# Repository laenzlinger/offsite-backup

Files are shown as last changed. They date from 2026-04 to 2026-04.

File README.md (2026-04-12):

# Granit — Offsite Backup Device

Custom carrier board for the Raspberry Pi CM4 Compute Module, designed as a minimal offsite backup appliance.

## Concept

A compact, headless device that connects to a remote network and receives encrypted backups onto an attached hard disk.
Designed to be left at a trusted offsite location (friend's house, office, etc.) and managed remotely.

This PCB is designed with [KiCad 10](https://www.kicad.org/blog/2026/03/Version-10.0.0-Released/)

## Hardware

### Core Components

| Component | Description |
|---|---|
| Raspberry Pi CM4 | Compute module (PCIe Gen 2 x1). CM5 mechanically compatible but not validated for power budget |
| ASM1061 | PCIe Gen 2 x1 to 2-port SATA III controller (no firmware blob required) |
| 2.5" or 3.5" SATA HDD/SSD | Backup storage |
| Amphenol 10029364-001LF | 22-pin SATA connector (data 7-pin + power 15-pin), right-angle |
| RJ45 + Ethernet magnetics | Gigabit Ethernet |
| DS3231 RTC | Battery-backed real-time clock with alarm wake (I2C) |
| CR2032 coin cell | RTC backup battery |
| RGB LED | Status indicator (idle/backup/error/maintenance) |
| Tactile button | Manual shutdown, trigger backup, enter maintenance mode on boot |
| Hirose DF40C-100DS-0.4V(51) | 2x CM4 board-to-board connectors |
| AP64501SP-13 | 3.5A DC-DC buck converter (reused from [pedalboard-hw](https://github.com/pedalboard/pedalboard-hw)) |
| USB-C | USB 2.0 OTG connector with USBLC6-2SC6 ESD protection |
| 2N7002 + 74AHCT1G32 | Hardware wake circuit (RTC alarm → GLOBAL_EN) and SATA power gate drivers |

### Block Diagram

Architecture Diagram

### PCB 3D Render

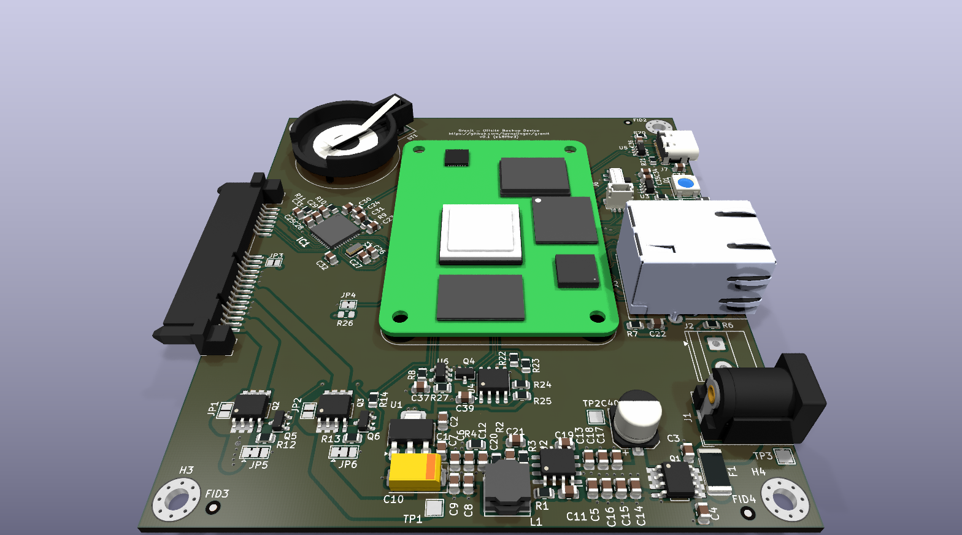
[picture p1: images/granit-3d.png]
PCB 3D


### Key Design Decisions

- **ASM1061 over USB-to-SATA bridges**: Native PCIe SATA controller using the standard Linux
  `ahci` driver. No proprietary firmware blob required — the SPI flash footprint can be left
  unpopulated. SMART works natively (`smartctl /dev/sda`) without SAT translation hacks.
  Both CM4 and CM5 have PCIe Gen 2 x1, so full SATA III throughput is available on either
  module — unlike USB-to-SATA, which would be bottlenecked by CM4's USB 2.0 (~35 MB/s).
- **12V DC input**: Required for 3.5" HDD support (spindle motor needs 12V).
  12V is passed through directly to the SATA power connector.
  AP64501SP-13 accepts 3.8–28V input, so 12V is well within range.
  Both barrel jack (Würth 6941xx301002) and screw terminal (Phoenix MKDS-1,5-2) footprints
  are provided — populate one at assembly time.
- **Reuse from pedalboard-hw**: CM connector, power supply (AP64501SP-13 buck + NCP1117 LDO),
  USB power switch (AP2553W6), KiCad symbol/footprint library, CI pipeline.
- **USB-C OTG**: Single USB-C connector for eMMC flashing (`rpiboot`) and USB mass storage
  gadget mode (initial backup seeding over USB). USB 2.0 device mode only, with USBLC6-2SC6
  ESD protection.
- **SATA power control**: 12V and 5V to the SATA connector are software-controlled via
  GPIO17. HDD is off by default at boot — powered on explicitly by software. Solder jumpers
  (JP5, JP6) allow changing the default to power-on at boot without a PCB respin.
- **Power budget**: 12V @ 2A (3.5" HDD spin-up) + 5V @ 2.3A peak (CM4 + electronics) — use a 12V/3A+ PSU.
- **Boot and storage strategy**: Full OS on CM4 eMMC (no SD card slot), SATA HDD dedicated
  to LUKS-encrypted backup storage only. HDD can spin down when idle. No SD card — eMMC is
  more reliable for a deploy-and-forget device. Reflashing via `nRPIBOOT` + USB-C if needed.

For detailed circuit design notes, PCB routing guidelines, and netclass definitions,
see [hardware/DESIGN.md](hardware/DESIGN.md).

## Software

The device runs Raspberry Pi OS Lite (headless).

### Planned Stack

- Restic backup repository (encryption built-in)
- rsync to receive backups from NAS
- `smartmontools` for disk health monitoring (`smartctl /dev/sda`)
- WireGuard VPN for remote management
- RTC-based scheduled wake: DS3231 alarm → GPIO4 interrupt → CM wakes from suspend → backup runs → suspend
  (`GLOBAL_EN` tied high via pull-up, CM4 uses Linux `rtcwake` for suspend/resume.
  Hardware power-off wake via MOSFET latch on `GLOBAL_EN` planned for v2.)
- LUKS full-disk encryption on the backup drive
- Automatic drive mount and health monitoring

### HDD Power Control

GPIO17 (`SATA_PWR_EN`) controls the P-FET power switches for the SATA 12V and 5V rails.
The boot default is selected by solder jumpers JP5 and JP6 (see Design Considerations above).

**Connect sequence** (power on → detect → mount):
```bash
#!/bin/bash
# Power on SATA rails (GPIO high → N-FET on → P-FET gate low → P-FET on)
gpioset gpiochip0 17=1
sleep 2

# Rescan AHCI bus (ASM1061 hot-plug)
echo "- - -" > /sys/class/scsi_host/host0/scan
sleep 3

# Unlock and mount
cryptsetup luksOpen /dev/sda1 backup
mount /dev/mapper/backup /mnt/backup
```

**Disconnect sequence** (unmount → spin down → power off):
```bash
#!/bin/bash
# Unmount and close LUKS
umount /mnt/backup
cryptsetup luksClose backup

# Spin down platters
hdparm -Y /dev/sda
sleep 1

# Remove SCSI device before power cut
echo 1 > /sys/block/sda/device/delete

# Power off SATA rails (GPIO low → N-FET off → pull-up → P-FET off)
gpioset gpiochip0 17=0
```

### Deployment

1. Initial backup on-site: connect Granit to local network, run full backup over LAN
2. Move device to offsite location (friend's house, office, etc.)
3. Plug in Ethernet + power — done
4. Subsequent backups are incremental and run automatically over WireGuard

### Monitoring & Alerting

Monitoring must live outside the Granit device — if the device fails, it can't alert about
its own failure. The device reports in after each backup run using a dead man's switch pattern:

- After each successful backup, Granit pings a healthcheck endpoint (e.g. self-hosted or healthchecks.io)
- If the expected ping doesn't arrive, an alert is triggered (email, push notification)
- Reported metrics: backup success/failure, SMART disk health, disk space remaining
- WireGuard connectivity is implicitly monitored — no tunnel means no ping

## Enclosure

Metal enclosure designed for a plug-and-forget deployment. The device should be installable
by a non-technical person: plug in Ethernet, plug in power, done.

### Hammond 1455 Series

Same PCB (92 × 100mm) fits both cases, held by a 3D printed internal frame.
PCB and HDD sit side-by-side along the enclosure length, SATA connector direct-mates between them.

| | 1455L2201 (Slim) | 1455T2601 (Wide) |
|---|---|---|
| Dimensions | 220 × 103 × 30.5 mm | 260 × 160 × 51.5 mm |
| Internal width | ~100 mm | ~157 mm |
| Internal height | ~27 mm | ~48 mm |
| HDD support | 2.5" only | 2.5" or 3.5" |
| Material | Extruded aluminium | Extruded aluminium |
| Colors | Natural, Black, Blue, Red | Natural, Black, Blue, Red |
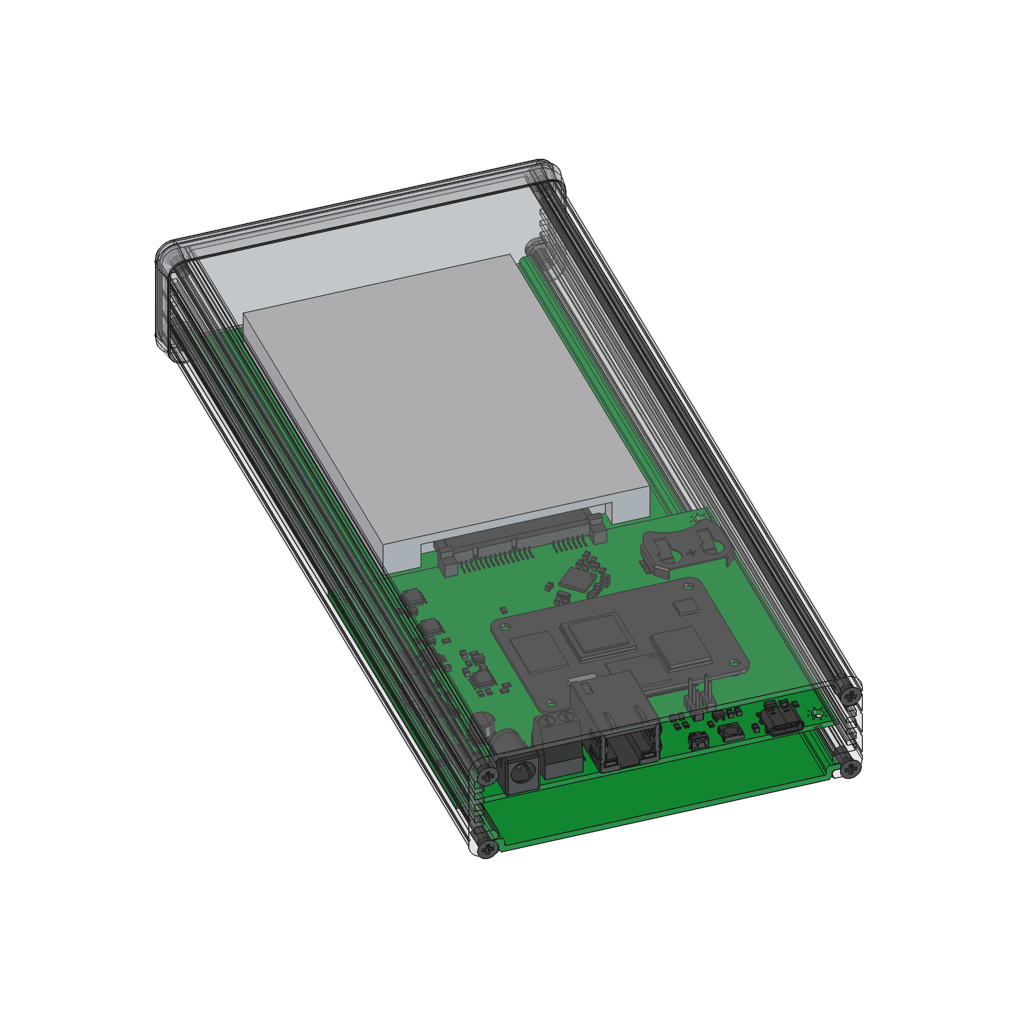
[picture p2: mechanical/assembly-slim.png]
Slim
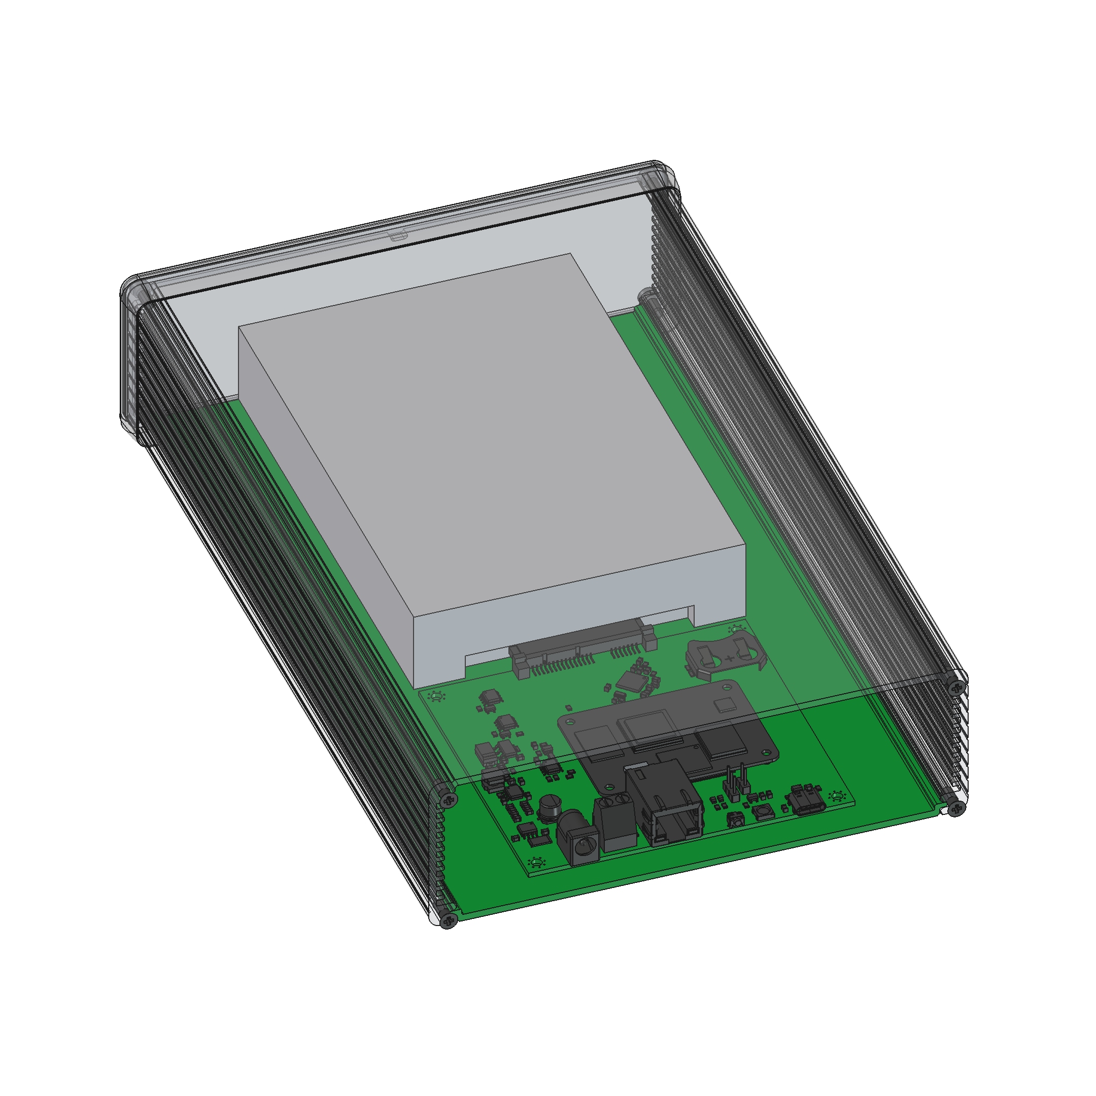
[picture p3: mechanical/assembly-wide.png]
Wide
| Assembly |  |  |

### Requirements

- Cutouts: barrel jack or screw terminal (12V), RJ45 (Ethernet), USB-C
- Tactile button accessible from outside (recessed to prevent accidental press)
- RGB LED visible through enclosure (light pipe or translucent window)
- Thermal pad or heatsink contact for CM4 SoC to enclosure lid
- Internal mounting for 2.5" or 3.5" HDD (M4 mounting holes)
- PCB standoffs (M3 mounting holes)

## Generated Hardware Documentation

Browse the latest generated outputs at **[laenzlinger.github.io/granit](https://laenzlinger.github.io/granit/)**.

Includes schematic PDF, interactive BOM, HTML BOM, and PCB prints — auto-generated on every push with [KiBot](https://github.com/INTI-CMNB/KiBot) (dev branch) running inside the official [kicad/kicad:10.0](https://hub.docker.com/r/kicad/kicad) container.

## License

[CERN Open Hardware Licence Version 2 - Permissive](https://ohwr.org/cern_ohl_p_v2.txt)

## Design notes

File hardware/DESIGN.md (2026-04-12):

# Hardware Design Notes

Detailed design decisions and PCB routing guidelines for the Granit carrier board.

## SATA Power Switching

12V and 5V to the SATA connector are switched by P-channel MOSFETs
(Q2, Q3 — FDS4435BZ). GPIO17 (`SATA_PWR_EN`) drives N-channel level shifters
(Q5, Q6 — 2N7002) which pull the P-FET gates low to turn them on.

```
Supply (+12V or +5VP)
  │
  JP5/JP6 pad 1 ─── [bridged default] ─── JP5/JP6 pad 2 (common)
                                              │
  JP5/JP6 pad 3 ─── GND                  R12/R13 (100K)
                                              │
                                         ┌────┴──── Q2/Q3 gate
                                         │
                                    2N7002 drain
                                         │
  SATA_PWR_EN (GPIO17) ── R14 (10K) ── 2N7002 gate
                                         │
                                    2N7002 source
                                         │
                                        GND
```

Two 3-pad solder jumpers (JP5 `SATA_12V_PWR`, JP6 `SATA_5V_PWR`) select the boot default:
- **Pads 1-2 bridged (default):** 100K pull-up to source → FETs OFF → HDD powered on by software
- **Pads 2-3 bridged:** 100K pull-down to GND → FETs ON → HDD powered at boot

GPIO17 high → N-FET on → P-FET gate low → SATA power on.
GPIO17 low or high-Z (boot default) → N-FET off → pull-up holds P-FET off.

R14 (10K) protects GPIO17 against N-FET gate-to-drain failure.

## Power Routing & Netclasses

PCB is fabricated with JLCPCB standard 4-layer stackup (1oz / 35µm copper on all layers).
Track widths are sized per IPC-2221 for outer-layer traces with 20°C temperature rise.

| Netclass | Track Width | Via (pad/drill) | Capacity (1oz, 20°C rise) | Worst-case Load | Nets |
|---|---|---|---|---|---|
| Power 12V | 3.0mm | 1.6mm / 0.8mm | ~3.5A | ~2.5A | `+12V*`, `fused`, `unfused` |
| Power 5V | 2.5mm | 1.6mm / 0.8mm | ~3.2A | ~2.8A | `+5VP`, `VBUS`, `switch` |
| Power 3V3 | 1.0mm | 0.8mm / 0.4mm | ~1.5A | ~0.6A | `+3V3` |

### Routing Guidelines

- Netclass widths are the default for main runs. Neck down to pad width over the last 1–2mm at component pads.
- Use copper pours for 12V and 5V in the PSU area where space allows.
- Use 2–3 parallel vias where power traces change layers.
- Place GND return vias near every power via.
- Keep 12V and 5V routing on top/bottom layers — do not break the inner GND planes.
- Do not route power traces under or parallel to PCIe/SATA/Ethernet differential pairs.

### Layer Strategy

- **Top layer:** PSU components and local routing, signal components
- **Inner 1 (In1.Cu):** GND plane — keep unbroken
- **Inner 2 (In2.Cu):** GND plane — keep unbroken
- **Bottom layer:** Power distribution (5V, 12V, 3.3V to rest of board), signal routing

### Signal Integrity

- **PCIe:** 100Ω differential impedance, matched length, minimize vias and stubs
- **SATA:** 100Ω differential impedance, matched length
- **Ethernet:** 100Ω differential impedance to RJ45 with magnetics
- **USB:** 90Ω differential impedance
- Power traces crossing differential pairs must cross perpendicular (90°)

### AC Coupling Capacitors

6× 100nF 0805 in series on high-speed differential pairs, all placed near the ASM1061:

- **SATA TX** (STXP_A, STXN_A): required by SATA spec (ASM1061 datasheet CTX = 75–200nF)
- **SATA RX** (SRXP_A, SRXN_A): defensive — external interface, can't guarantee drive-side caps
- **PCIe RX** (PCIE_RX_P, PCIE_RX_N): required by CM4 datasheet ("external AC coupling capacitor required")
- **PCIe TX, CLK**: not needed — CM4 has internal AC coupling
- **Ethernet**: not needed — MagJack provides galvanic isolation
- **USB**: not needed — DC-coupled by spec

### ESD Protection

- **USB-C** (J7): USBLC6-2SC6 on D+/D− — user-facing external connector, required
- **SATA** (J9): no ESD protection — internal connector inside metal enclosure, not user-accessible, AC coupling caps provide DC fault isolation
- **Ethernet** (J3): RJ45 MagJack has integrated common-mode chokes and 2kV isolation

## Power Budget

| Rail | Source | Capacity | Worst-case Load |
|---|---|---|---|
| 12V | External PSU | 3A+ recommended | ~2.5A (HDD spin-up + buck converter) |
| 5V | AP64501SP-13 | 3.5A | ~2.8A (CM4 + HDD + USB) |
| 3.3V | NCP1117 LDO | 1A | ~0.6A (ASM1061 + RTC + misc) |

Realistic steady state: ~1.5A (CM4) + 0.5A (HDD) = 2.0A on 5V rail.
HDD spin-up and CM4 peak don't occur simultaneously — SATA power is software-controlled.

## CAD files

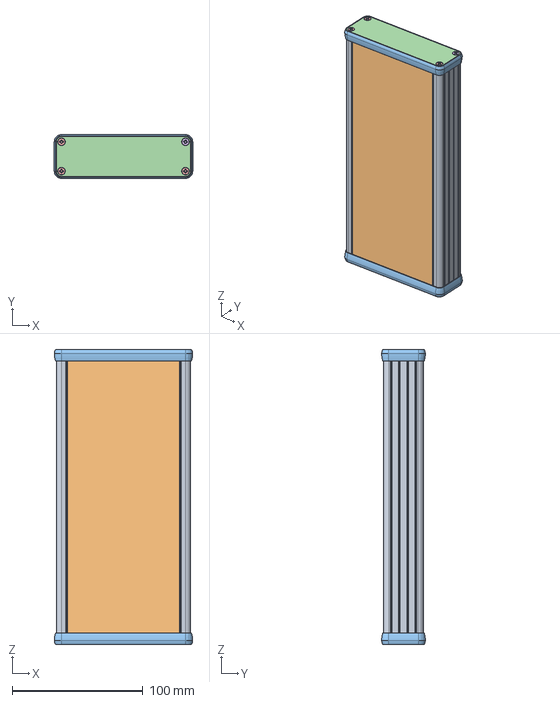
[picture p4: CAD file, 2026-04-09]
mechanical/assembly-slim.step
106.1 x 33.6 x 226.0 mm

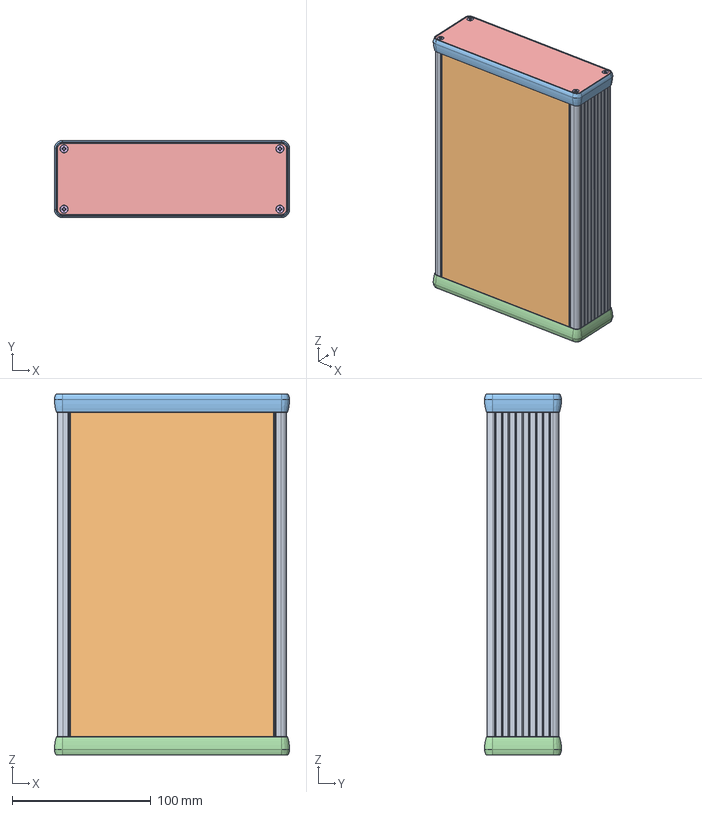
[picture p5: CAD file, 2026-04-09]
mechanical/assembly-wide.step
169.5 x 55.6 x 260.0 mm

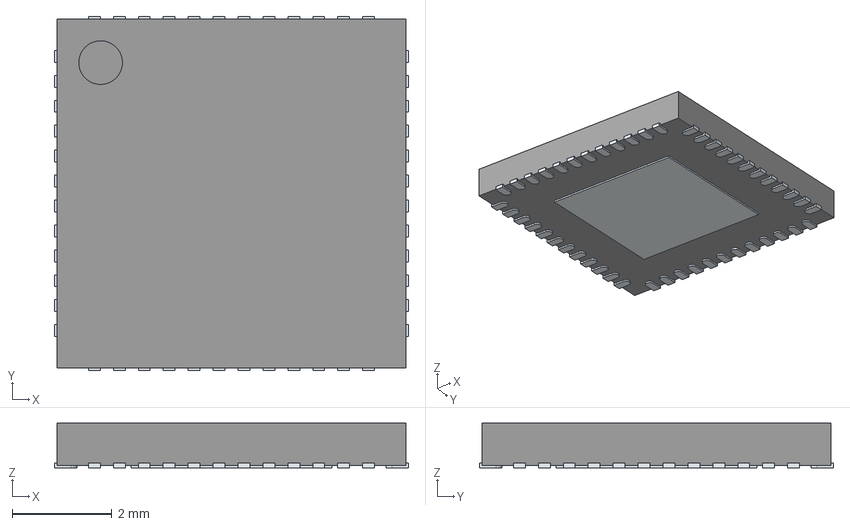
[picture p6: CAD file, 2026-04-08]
hardware/3d-models/ASM1061.stp
7.10 x 7.10 x 0.9 mm
ThermalPin
PinsArrayLR
PinsArrayTB

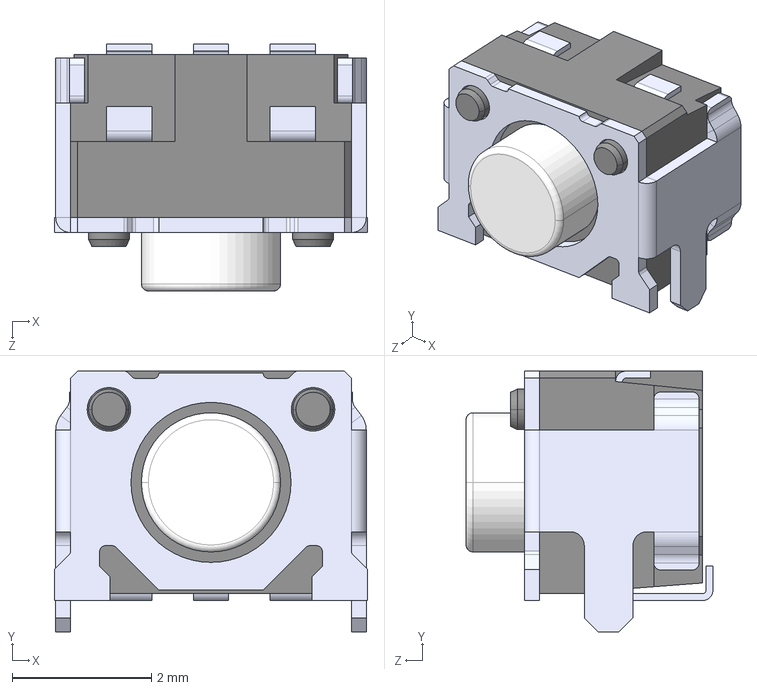
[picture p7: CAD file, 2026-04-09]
hardware/3d-models/SW_Alps_SKRTLAE010.step
4.50 x 3.75 x 3.55 mm

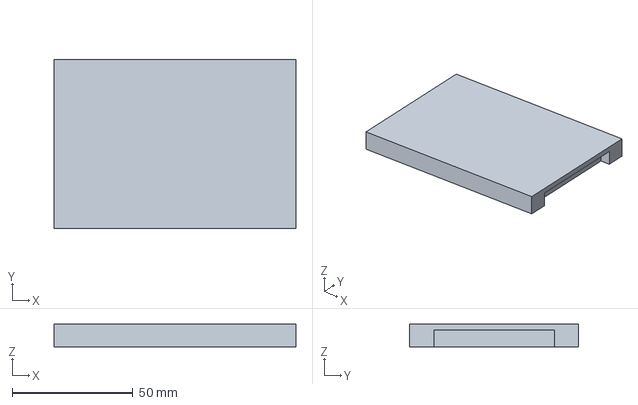
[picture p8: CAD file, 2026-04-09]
mechanical/2.5inch_HDD.step
100.2 x 69.8 x 9.50 mm

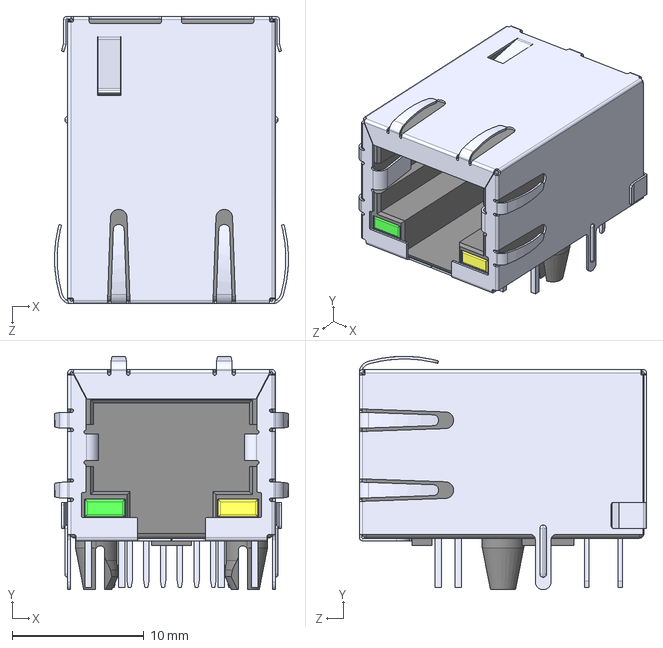
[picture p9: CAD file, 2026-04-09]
hardware/3d-models/RJ45_UDE_RB1-125B8G1A.step
17.7 x 17.7 x 21.8 mm

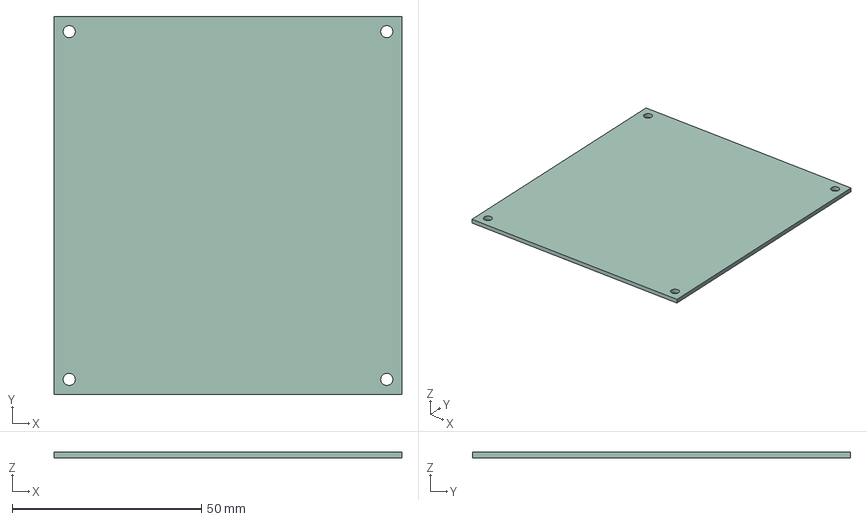
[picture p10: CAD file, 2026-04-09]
mechanical/granit-pcb.step
92.0 x 100.0 x 1.52 mm

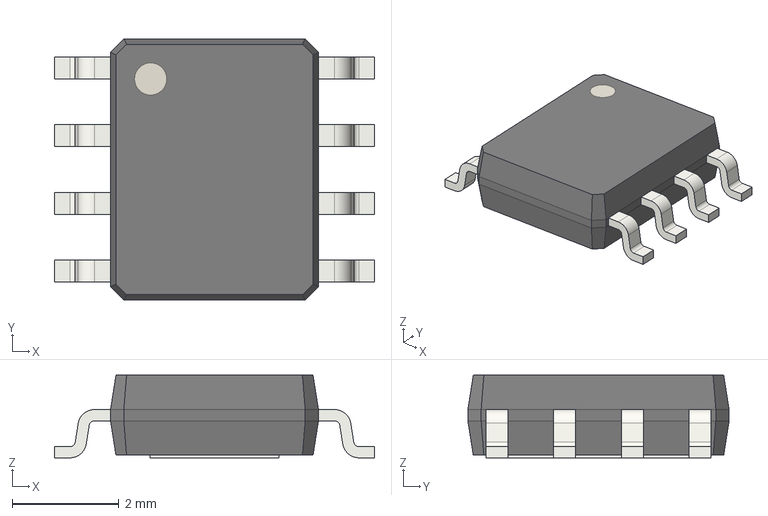
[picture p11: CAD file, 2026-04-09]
hardware/3d-models/SO-8EP.STP
6.00 x 4.90 x 1.55 mm

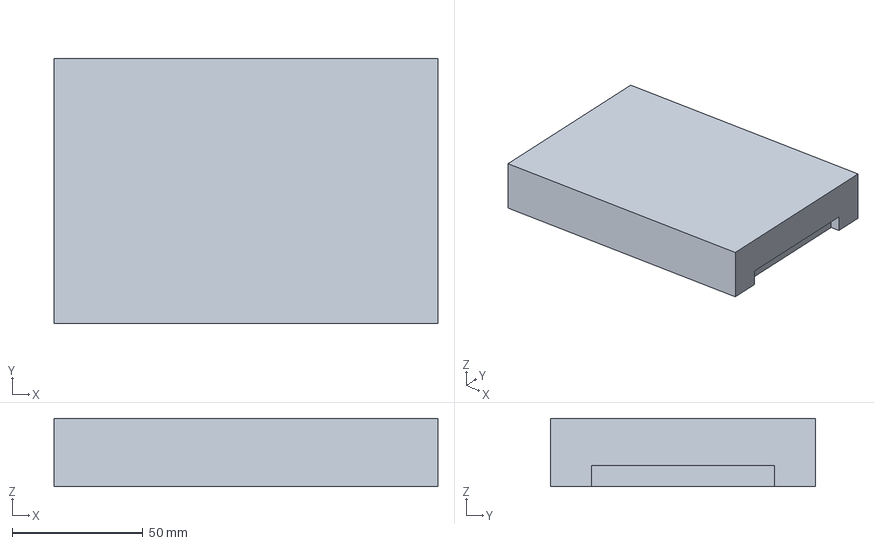
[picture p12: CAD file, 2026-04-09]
mechanical/3.5inch_HDD_NAS.step
147.0 x 101.6 x 26.1 mm

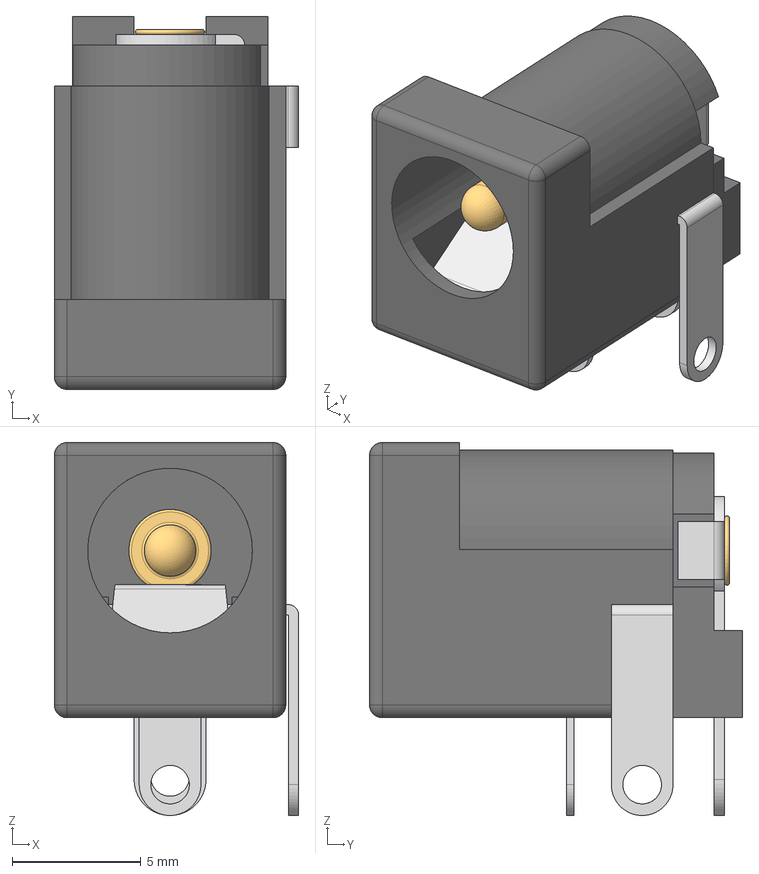
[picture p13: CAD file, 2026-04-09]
hardware/3d-models/694106301002 (rev1).stp
9.50 x 14.5 x 14.5 mm
6941xx301002
694106301002_PinContact
6941xx301002_Back
6941xx301002_PinContact2
6941xx301002_PinLame
6941xx301002_PinBis

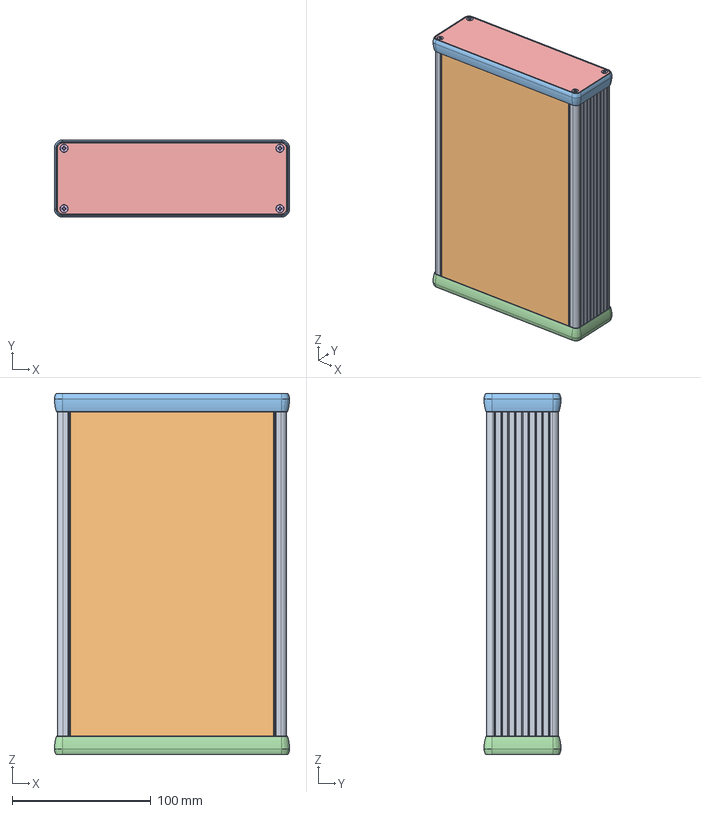
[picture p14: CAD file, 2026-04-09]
hardware/3d-models/1455T2601.stp
169.5 x 55.6 x 260.0 mm

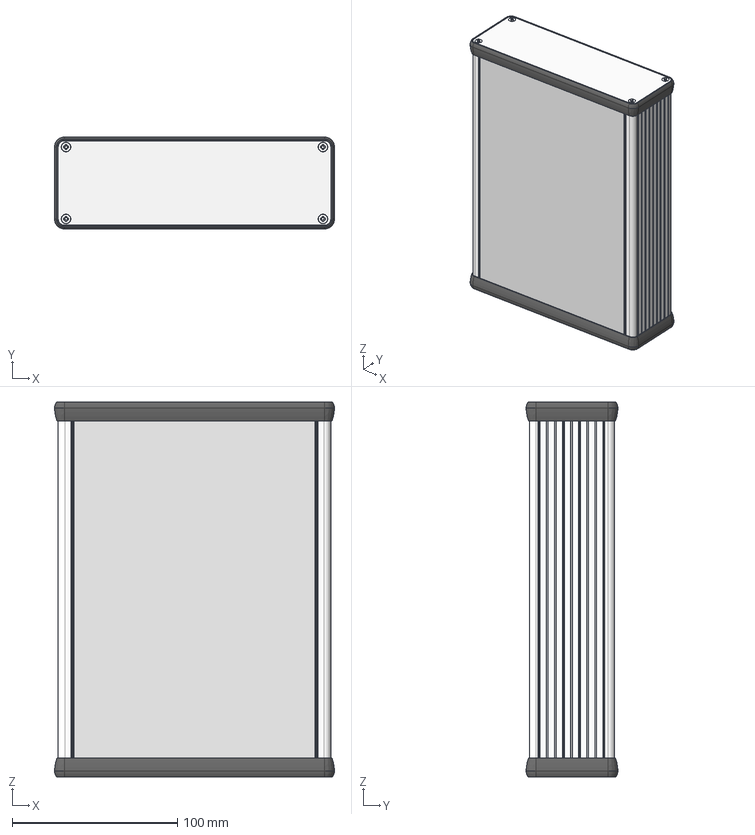
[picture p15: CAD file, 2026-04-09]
hardware/3d-models/1455T2201.stp
169.5 x 55.6 x 227.0 mm
T extrusion 220mm
T Extrusion Cap 220mm
T Bezel Open x 2
T End Plate x 2
1455 screw x 8

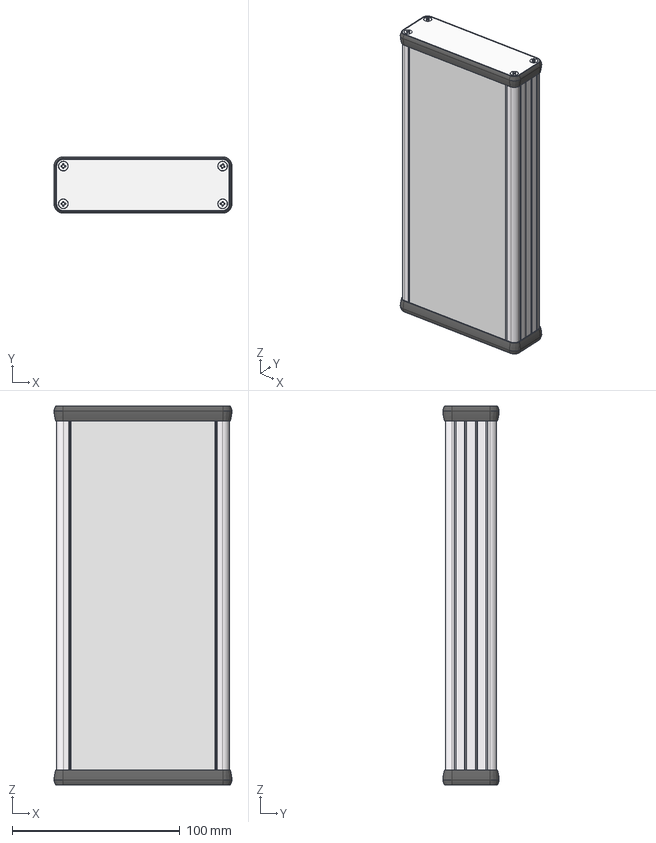
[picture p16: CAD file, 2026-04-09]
hardware/3d-models/1455L2201.stp
106.1 x 33.6 x 226.0 mm
L Extrusion 220mm
L Cap Extrusion 220mm
N Bezel x 2
N1 End Panel x 2
1455 screw x 8

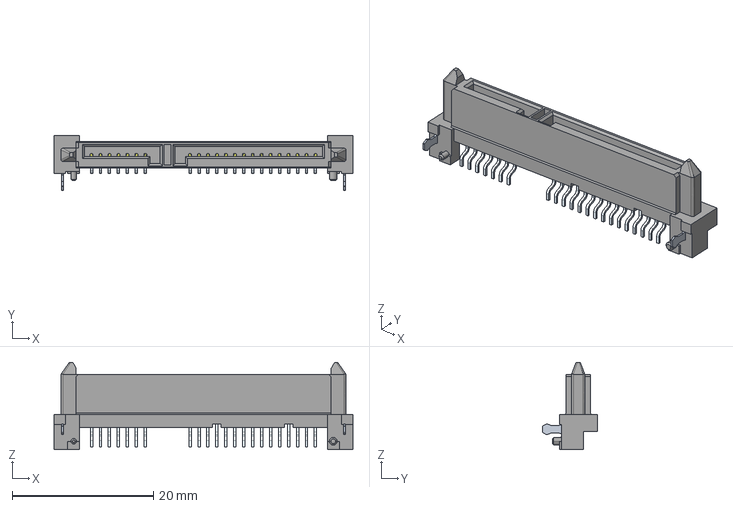
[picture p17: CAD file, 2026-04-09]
hardware/3d-models/i10029364001LF.igs
42.4 x 7.82 x 12.4 mm

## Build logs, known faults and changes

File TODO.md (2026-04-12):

# Granit — TODO

## Schematic ✅

### Done

- [x] PSU: AP64501SP-13 buck + NCP1117 LDO + FDS4435BZ reverse polarity + 3A SMD fuse
- [x] CM4 Connector 1: power, GND, NC flags, global labels, Ethernet, GLOBAL_EN
- [x] CM4 Connector 2: power, GND, NC flags, global labels, USB, PCIe
- [x] Peripherals: SK6812MINI-E NeoPixel + 74AHCT1G32 level shifter
- [x] Peripherals: status LEDs (nLED_PWR, nLED_ACT, DNP)
- [x] Peripherals: tactile button (GPIO17) + pull-up
- [x] Peripherals: nRPIBOOT PCM12SMTR slide switch
- [x] Peripherals: UART debug JST-SH 3-pin (BM03B-SRSS-TB vertical)
  - FIXME: pinout is TX-RX-GND (pins 1-2-3), standard convention is GND-TX-RX
- [x] Peripherals: DS3231MZ RTC + CR2032 battery
- [x] Peripherals: USB-C OTG + USBLC6-2SC6 ESD protection + solder jumper
- [x] Ethernet: RB1-125B8G1A Gigabit MagJack + LEDs
- [x] SATA: ASM1061 PCIe-to-SATA bridge + 25MHz crystal
- [x] SATA: add 100nF AC coupling caps (0805) in series on SATA TX pair (STXP_A, STXN_A), placed near ASM1061 — required by SATA spec (ASM1061 datasheet CTX = 75–200nF)
- [x] SATA: add 100nF AC coupling caps (0805) in series on SATA RX pair (SRXP_A, SRXN_A), placed near ASM1061 — defensive, external interface can't guarantee drive-side caps
- [x] PCIe: add 100nF AC coupling caps (0805) in series on PCIe RX pair (PCIE_RX_P, PCIE_RX_N), placed near ASM1061 TX output — CM4 datasheet: "external AC coupling capacitor required"
- [x] SATA: 7-pin data connector + 4-pin power connector
- [x] SATA: power switching (FDS4435BZ on 5V/12V, GPIO5 controlled, solder jumper bypass)
- [x] Wake: hardware power-off wake (2N7002 + 74AHCT1G32 OR gate, DNP for v1)
- [x] All footprints assigned
- [x] All component descriptions filled
- [x] Resistor values consolidated (9 unique)
- [x] All decoupling caps verified
- [x] ERC: 0 errors, 0 warnings
- [x] ERC enabled in CI

## PCB Layout

Side-by-side layout inside Hammond 1455L2201 (220mm length):

- HDD occupies 147mm, PCB sits in the remaining space
- SATA connector on PCB edge mates directly with HDD
- External connectors (RJ45, USB-C, barrel jack, button) on opposite end panel

Max PCB size: **71 × 99mm** (fits 1455L card guides at 99.5mm — compatible with both cases)

Both PCB and HDD mount independently to the belly plate (slide-out for servicing).

### Component floorplan

```
                    SATA edge (faces HDD)
    ┌─────────────────────────────────────────┐
    │                                         │
    │   ASM1061        SATA connector         │
    │   (7×7mm)        (42mm wide, edge)      │
    │      ↕ short SATA diff pairs            │
    │                                         │
    │   ────── PCIe diff pairs (~20mm) ────── │
    │                                         │
    │          CM4 module (55×40mm)            │
    │          (center of board)              │
    │                                         │
    │   ↕ short ETH     ↕ USB        PSU     │
    │   diff pairs       diff        area    │
    │                                         │
    │  RJ45  USB-C  Barrel  BTN  LED  CR2032 │
    │                                         │
    └─────────────────────────────────────────┘
                 Connector edge (end plate)
```

Placement rationale:

- ASM1061 near SATA edge → shortest SATA differential pairs
- CM4 center → PCIe north to ASM1061, Ethernet south to RJ45
- RJ45 + USB-C on connector edge → short diff pairs from CM4
- PSU in corner → switching noise away from high-speed signals
- DS3231 + CR2032 → quiet area near CM4 I2C pins
- Button + LED → connector edge, accessible through end plate

### Pre-routing: stackup and impedance (JLCPCB 4-layer)

[JLCPCB JLC04161H-7628 standard 4-layer stackup](https://jlcpcb.com/impedance) (1.6mm):

| Layer | Material | Thickness | Er |
|---|---|---|---|
| Solder mask | — | 0.6mil above trace | 3.8 |
| L1 (Top signal) | Copper | 35µm (1oz) | — |
| Prepreg | 7628 | 0.2104mm | 4.4 |
| L2 (GND plane) | Copper | 35µm (1oz) | — |
| Core | — | 1.065mm | 4.6 |
| L3 (Power plane) | Copper | 35µm (1oz) | — |
| Prepreg | 7628 | 0.2104mm | 4.4 |
| L4 (Bottom signal) | Copper | 35µm (1oz) | — |
| Solder mask | — | 0.6mil above trace | 3.8 |

Trace geometry from [JLCPCB impedance calculator](https://jlcpcb.com/impedance)
(L1 signal, L2 GND reference, 0.2104mm prepreg, Er=4.6, 1oz outer / 0.5oz inner copper):
- 100Ω differential (PCIe, SATA, Ethernet): **0.2205mm trace, 0.2032mm gap**
- 90Ω differential (USB): **0.2860mm trace, 0.2032mm gap**

[JLCPCB capabilities](https://jlcpcb.com/capabilities/pcb-capabilities):
min 0.09mm trace/space, 0.2mm drill, 0.13mm annular ring.

- [x] Choose fab house: JLCPCB (prototype)
- [x] Update KiCad net classes with calculated values:
  - PCIe: diff_pair_width=0.2205, diff_pair_gap=0.2032
  - SATA: diff_pair_width=0.2205, diff_pair_gap=0.2032
  - Ethernet: diff_pair_width=0.2205, diff_pair_gap=0.2032
  - USB: diff_pair_width=0.2860, diff_pair_gap=0.2032
- [ ] Select impedance control when ordering (+~$10)
- [x] PCB thickness: 1.6mm (standard)

### Checklist

PCB standoff height must match HDD SATA connector vertical position (~3.5mm above belly plate).

- [x] Board outline: 92 × 100mm (fits 1455L slim and 1455T2601 wide cases)
- [x] Verify PCB standoff height aligns SATA connector with HDD receptacle
- [x] 4-layer stackup (signal/GND/power/signal)
- [x] SATA connector: replaced J4+J5 with single 22-pin Amphenol 10029364-001LF (horizontal/right-angle)
  - Footprint: `Connector_SATA_SAS:SATA_Amphenol_10029364-001LF_Horizontal`
  - Symbol: `granit:SATA_22pin`
- [x] External connectors (RJ45, USB-C, barrel jack, button, LED) on opposite edge
- [x] Place CM4 module and all components on top side (facing lid, for thermal contact)
- [x] SATA connector vertical alignment: HDD connector center is 3.50mm above mounting surface (SFF-8301)
  - Use matching standoff height for PCB and HDD (e.g. 5mm) — keeps SATA aligned
  - 5mm standoffs: CR2032 (3.4mm) fits on bottom side ✅
  - 1455L: 5mm + 9.5mm (2.5" HDD) = 14.5mm, 12.5mm to ceiling ✅
  - 1455T: 5mm + 26.1mm (3.5" HDD) = 31.1mm, 17mm to ceiling ✅
- [x] CR2032 holder on bottom side (fits under 5mm standoffs)
- [x] Place ASM1061 near SATA connector (short differential pairs)
- [ ] HDD mounting holes: M4 (4.3mm drill, `MountingHole:MountingHole_4.3mm_M4_Pad_Via`)
- [x] PCB standoff holes: M3 (3.2mm drill, `MountingHole:MountingHole_3.2mm_M3_Pad_Via`)
- [ ] Mounting hole keepout: 7.0mm clearance on pads (prevent screw heads shorting 12V traces)
- [x] Route PCIe differential pairs (100Ω impedance)
- [x] Route SATA differential pairs
- [x] Route Ethernet differential pairs
- [x] Route USB differential pairs
- [x] Power trace width: ≥1.0mm (40 mil) for short branches to pads
- [ ] Power planes on L3: split into 5V and 3.3V zones
- [ ] 12V: copper pour on L4 from barrel jack to SATA power (2A+ spin-up)
- [x] GND: solid plane on L2, stitching vias throughout
- [x] GND stitching: increase via density to 3–5/cm² (currently 1.2/cm²). 3mm grid near high-speed (PCIe/SATA/ETH), 5mm elsewhere. Use Place → Add Board Stitching Vias.
- [x] DRC clean (0 violations, 46 justified exclusions)
- [ ] Silkscreen: add labels for switch positions (RUN/BOOT), jumper functions (JP1–JP6), connector pinouts (J8 UART), polarity markings, and board name/revision
- [ ] Silkscreen front: add QR code or barcode linking to project URL (https://github.com/laenzlinger/granit)
- [ ] Silkscreen back: add stackup info (layer order, impedance targets, fab spec JLC04161H-7628)

## Enclosure

- [x] Case: Hammond 1455T2201 (3.5" HDD) or 1455L2201 (2.5" HDD only)
- [ ] 3D-printed internal frame (slides into case card guide grooves)
  - Holds PCB and HDD at correct height (5mm standoff equivalent)
  - Different frame variants for 2.5" vs 3.5" HDD
  - No belly plate drilling, no standoffs, no CNC needed
- [ ] CNC end plate: cutouts for RJ45, USB-C, barrel jack, button, LED
- [ ] Thermal pad from CM4 SoC to enclosure lid

## Future Improvements

- [ ] TPM/crypto chip (e.g. ATECC608) for secure LUKS key storage (I2C)
- [ ] Evaluate CM5 compatibility (power budget validation)
- [ ] Power LED on fused 12V rail (troubleshooting: PSU present but buck failed)
- [ ] Review fuse rating: 3A may be tight for 3.5" NAS drives (1.8–2.5A spin-up) + CM4 on same rail — consider 4A or inrush limiter
- [ ] Verify ASM1061 exposed pad thermal vias to ground plane (0.5W under sustained SATA III)
- [ ] Read-only root filesystem (overlayfs) to survive power loss — eMMC-only boot has no fallback
- [ ] Second SATA data connector (7-pin) for ASM1061 port B — enables RAID1 or dual-drive backup

## CI/CD

- [x] KiBot artifact generation with KiCad 10
- [x] GitHub Pages deployment (<https://laenzlinger.github.io/granit/>)
- [x] ERC check in KiBot preflight
- [x] Enable DRC check when PCB layout is complete
- [ ] Switch to kicad10_auto container when available
- [ ] Add 3D renders (blender_export) once ghcr.io/inti-cmnb/kicad10_auto_full image exists (see pedalboard-hw)

## Software

- [ ] Raspberry Pi OS Lite base image
- [ ] Enable BCM2711 hardware watchdog (`bcm2835_wdt`) — critical for unattended remote device
- [ ] Device tree overlay for ASM1061
- [ ] DS3231 RTC driver + alarm configuration
- [ ] DS3231 OSF flag check on boot (warn if battery failed, report via healthcheck)
- [ ] GPIO_HOLD (GPIO6) assertion on boot
- [ ] SATA_PWR_EN (GPIO17) control
- [ ] NeoPixel status daemon
- [ ] Button handler (shutdown/backup/maintenance)
- [ ] WireGuard VPN configuration
- [ ] Restic backup automation
- [ ] LUKS encrypted backup partition
- [ ] Healthcheck dead man's switch
- [ ] SMART disk monitoring
- [ ] rtcwake integration for scheduled power-off/wake

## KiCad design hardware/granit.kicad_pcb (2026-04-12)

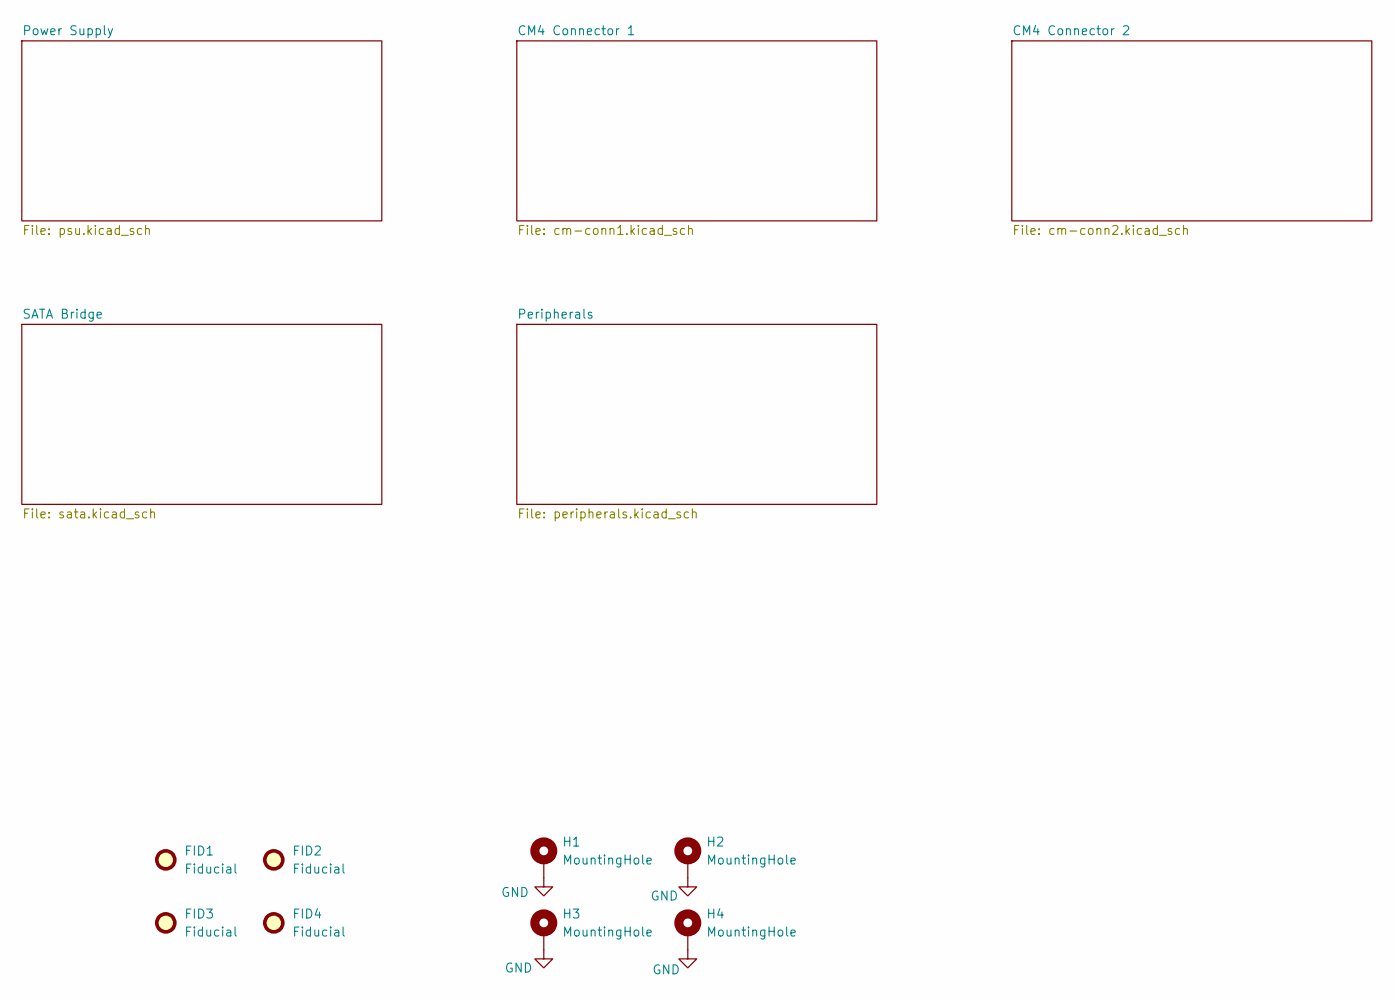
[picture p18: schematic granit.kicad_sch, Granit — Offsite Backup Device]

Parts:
FID1, FID2, FID3, FID4: Fiducial; Fiducial_1mm_Mask2mm
H1, H2, H3, H4: MountingHole; MountingHole_3.2mm_M3_Pad_Via

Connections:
GND: H1.1 (1_1), H2.1 (1_1), H3.1 (1_1), H4.1 (1_1); also elsewhere on the board

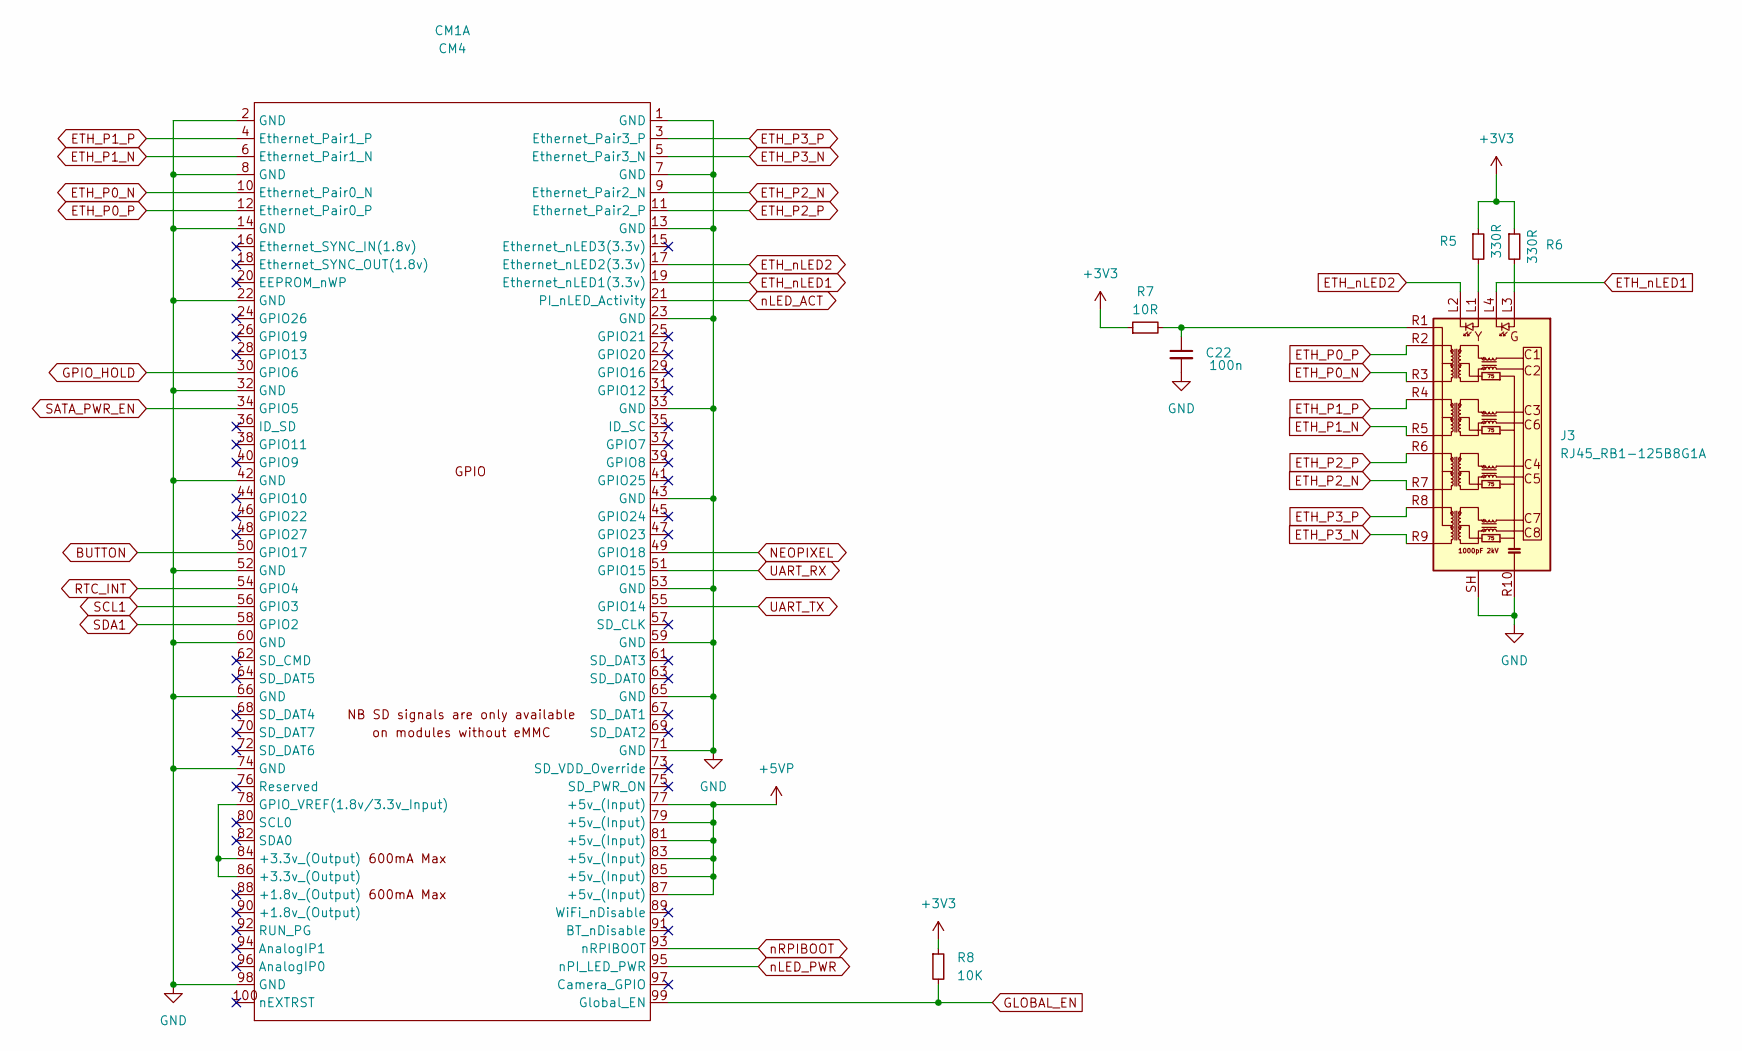
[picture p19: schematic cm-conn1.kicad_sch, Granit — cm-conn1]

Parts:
C22: 100n; C_0805_2012Metric; Digikey 1276-1180-1-ND
CM1: CM4; Raspberry-Pi-4-Compute-Module
J3: RJ45_RB1-125B8G1A; RJ45_UDE_RB1-125B8G1A
R5, R6: 330R; R_0805_2012Metric
R7: 10R; R_0805_2012Metric
R8: 10K; R_0805_2012Metric

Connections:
+3V3: R5.1, R6.1, R7.1, R8.1; also elsewhere on the board
+5VP: CM1.77 (+5v_(Input)), CM1.79 (+5v_(Input)), CM1.81 (+5v_(Input)), CM1.83 (+5v_(Input)), CM1.85 (+5v_(Input)), CM1.87 (+5v_(Input)); also elsewhere on the board
BUTTON: CM1.50 (GPIO17); also elsewhere on the board
ETH_P0_N: CM1.10 (Ethernet_Pair0_N), J3.R3 (TD1-)
ETH_P0_P: CM1.12 (Ethernet_Pair0_P), J3.R2 (TD1+)
ETH_P1_N: CM1.6 (Ethernet_Pair1_N), J3.R5 (TD2-)
ETH_P1_P: CM1.4 (Ethernet_Pair1_P), J3.R4 (TD2+)
ETH_P2_N: CM1.9 (Ethernet_Pair2_N), J3.R7 (TD3-)
ETH_P2_P: CM1.11 (Ethernet_Pair2_P), J3.R6 (TD3+)
ETH_P3_N: CM1.5 (Ethernet_Pair3_N), J3.R9 (TD4-)
ETH_P3_P: CM1.3 (Ethernet_Pair3_P), J3.R8 (TD4+)
ETH_nLED1: CM1.19 (Ethernet_nLED1(3.3v)), J3.L4
ETH_nLED2: CM1.17 (Ethernet_nLED2(3.3v)), J3.L2
GLOBAL_EN: CM1.99 (Global_EN), R8.2; also elsewhere on the board
GND: C22.2, CM1.1 (GND), CM1.2 (GND), CM1.7 (GND), CM1.8 (GND), CM1.13 (GND), CM1.14 (GND), CM1.22 (GND), CM1.23 (GND), CM1.32 (GND), CM1.33 (GND), CM1.42 (GND), CM1.43 (GND), CM1.52 (GND), CM1.53 (GND), CM1.59 (GND), CM1.60 (GND), CM1.65 (GND), CM1.66 (GND), CM1.71 (GND), CM1.74 (GND), CM1.98 (GND), J3.R10 (GND), J3.SH; also elsewhere on the board
GPIO_HOLD: CM1.30 (GPIO6); also elsewhere on the board
NEOPIXEL: CM1.49 (GPIO18); also elsewhere on the board
unnamed: CM1.78 (GPIO_VREF(1.8v/3.3v_Input)), CM1.84 (+3.3v_(Output)), CM1.86 (+3.3v_(Output))
unnamed: C22.1, J3.R1 (CT), R7.2
unnamed: J3.L1, R5.2
unnamed: J3.L3, R6.2
RTC_INT: CM1.54 (GPIO4); also elsewhere on the board
SATA_PWR_EN: CM1.34 (GPIO5); also elsewhere on the board
SCL1: CM1.56 (GPIO3); also elsewhere on the board
SDA1: CM1.58 (GPIO2); also elsewhere on the board
UART_RX: CM1.51 (GPIO15); also elsewhere on the board
UART_TX: CM1.55 (GPIO14); also elsewhere on the board
nLED_ACT: CM1.21 (PI_nLED_Activity); also elsewhere on the board
nLED_PWR: CM1.95 (nPI_LED_PWR); also elsewhere on the board
nRPIBOOT: CM1.93 (nRPIBOOT); also elsewhere on the board

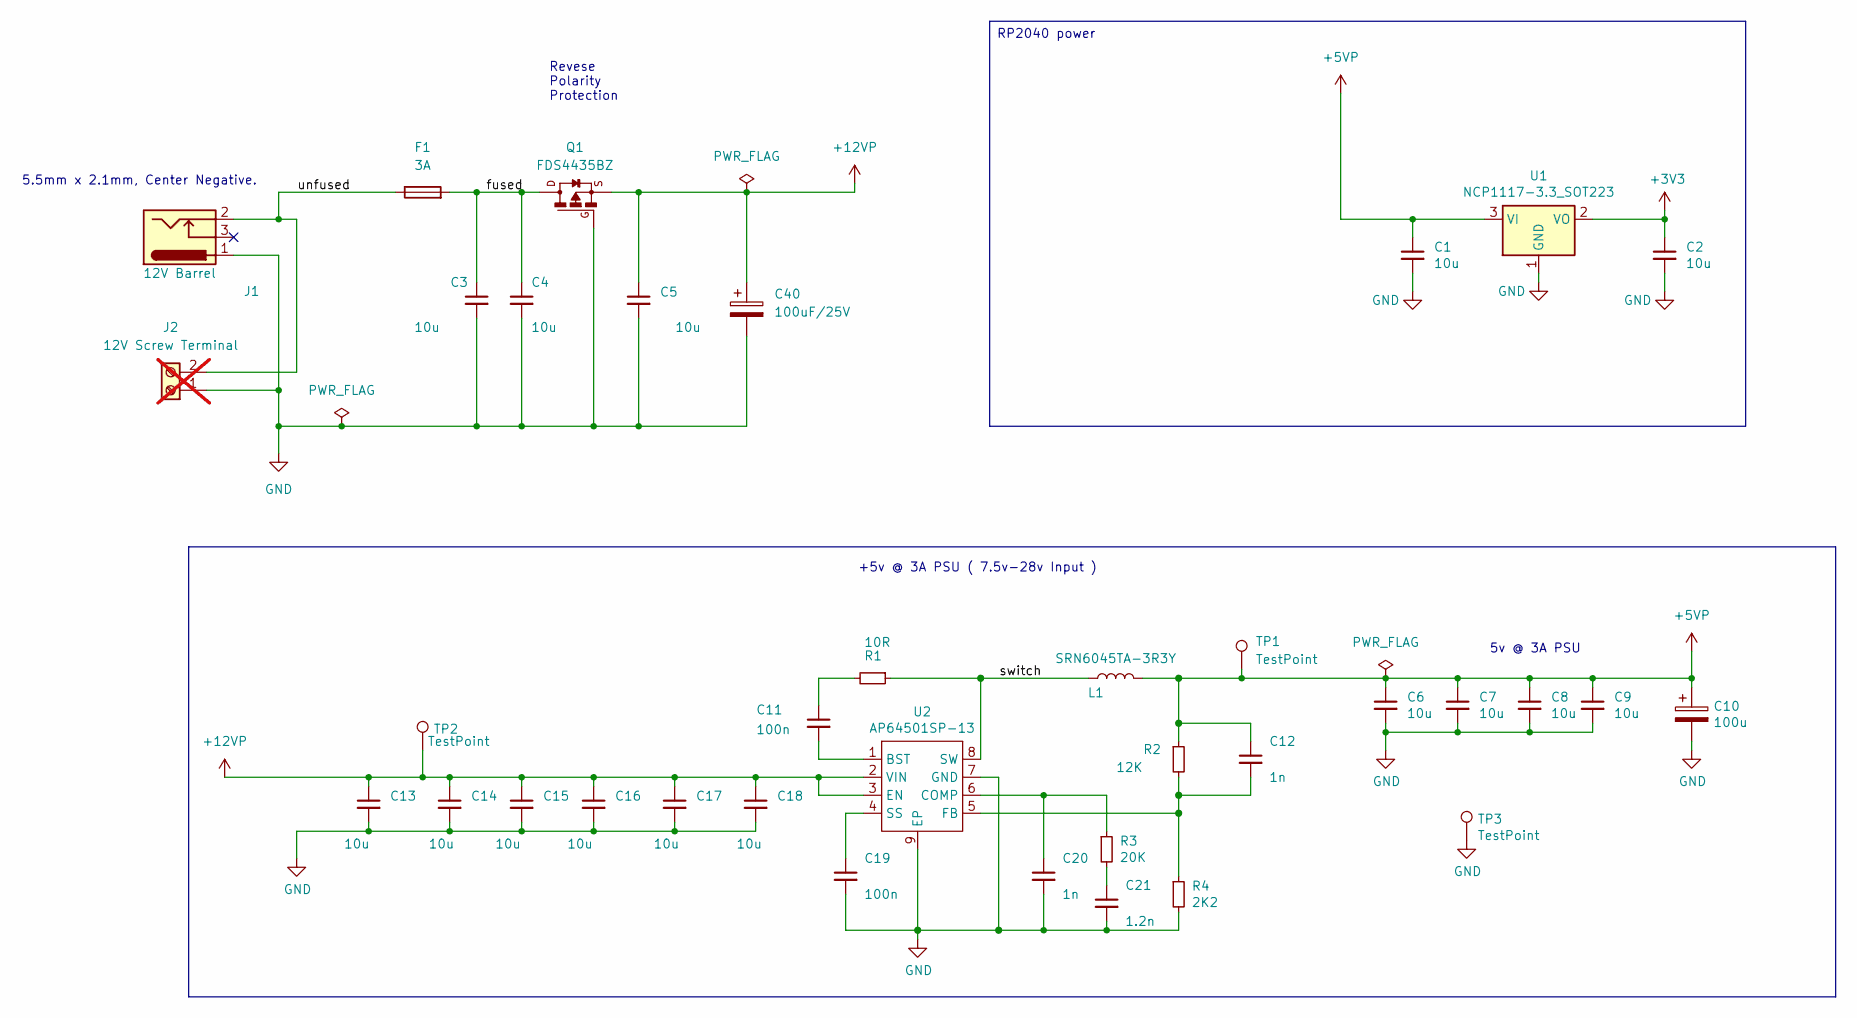
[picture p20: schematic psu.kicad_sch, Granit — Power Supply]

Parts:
C1, C2, C3, C4, C5, C6, C7, C8, C9, C13, C14, C15, C16, C17, C18: 10u; C_0805_2012Metric
C10: 100u; CP_EIA-7343-31_Kemet-D
C11, C19: 100n; C_0805_2012Metric; Digikey 1276-1180-1-ND
C12, C20: 1n; C_0805_2012Metric
C21: 1.2n; C_0805_2012Metric
C40: 100uF/25V; CP_Elec_6.3x5.8
F1: 3A; Fuse_2512_6332Metric
J1: 12V Barrel; BarrelJack_Wuerth_6941xx301002
J2: 12V Screw Terminal; TerminalBlock_Phoenix_MKDS-1,5-2_1x02_P5.00mm_Horizontal; not fitted
L1: SRN6045TA-3R3Y; L_Bourns_SRN6045TA
Q1: FDS4435BZ; SO08-E3
R1: 10R; R_0805_2012Metric
R2: 12K; R_0805_2012Metric
R3: 20K; R_0805_2012Metric
R4: 2K2; R_0805_2012Metric
TP1, TP2, TP3: TestPoint; TestPoint_Pad_2.0x2.0mm
U1: NCP1117-3.3_SOT223; SOT-223-3_TabPin2
U2: AP64501SP-13; SOIC-8-1EP_3.9x4.9mm_P1.27mm_EP2.95x4.9mm_Mask2.71x3.4mm_Th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

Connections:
+3V3: C2.1, U1.2 (VO); also elsewhere on the board
+5VP: C1.1, C6.1, C7.1, C8.1, C9.1, C10.1, C12.1, L1.2, R2.1, TP1.1 (1_1), U1.3 (VI); also elsewhere on the board
+12VP: C5.1, C13.1, C14.1, C15.1, C16.1, C17.1, C18.1, C40.1, Q1.1-3, TP2.1 (1_1), U2.2 (VIN), U2.3 (EN); also elsewhere on the board
/Power Supply/fused: C3.1, C4.1, F1.2, Q1.5-8
/Power Supply/switch: L1.1, R1.1, U2.8 (SW)
/Power Supply/unfused: F1.1, J1.2, J2.2
GND: C1.2, C2.2, C3.2, C4.2, C5.2, C6.2, C7.2, C8.2, C9.2, C10.2, C13.2, C14.2, C15.2, C16.2, C17.2, C18.2, C19.2, C20.2, C21.2, C40.2, J1.1, J2.1, Q1.4, R4.2, TP3.1 (1_1), U1.1 (GND), U2.7 (GND), U2.9 (EP); also elsewhere on the board
unnamed: C11.1, R1.2
unnamed: C21.1, R3.2
unnamed: C11.2, U2.1 (BST)
unnamed: C20.1, R3.1, U2.6 (COMP)
unnamed: C12.2, R2.2, R4.1, U2.5 (FB)
unnamed: C19.1, U2.4 (SS)

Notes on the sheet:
5v @ 3A PSU
+5v @ 3A PSU ( 7.5v-28v Input )
Revese Polarity Protection
5.5mm x 2.1mm, Center Negative.
RP2040 power

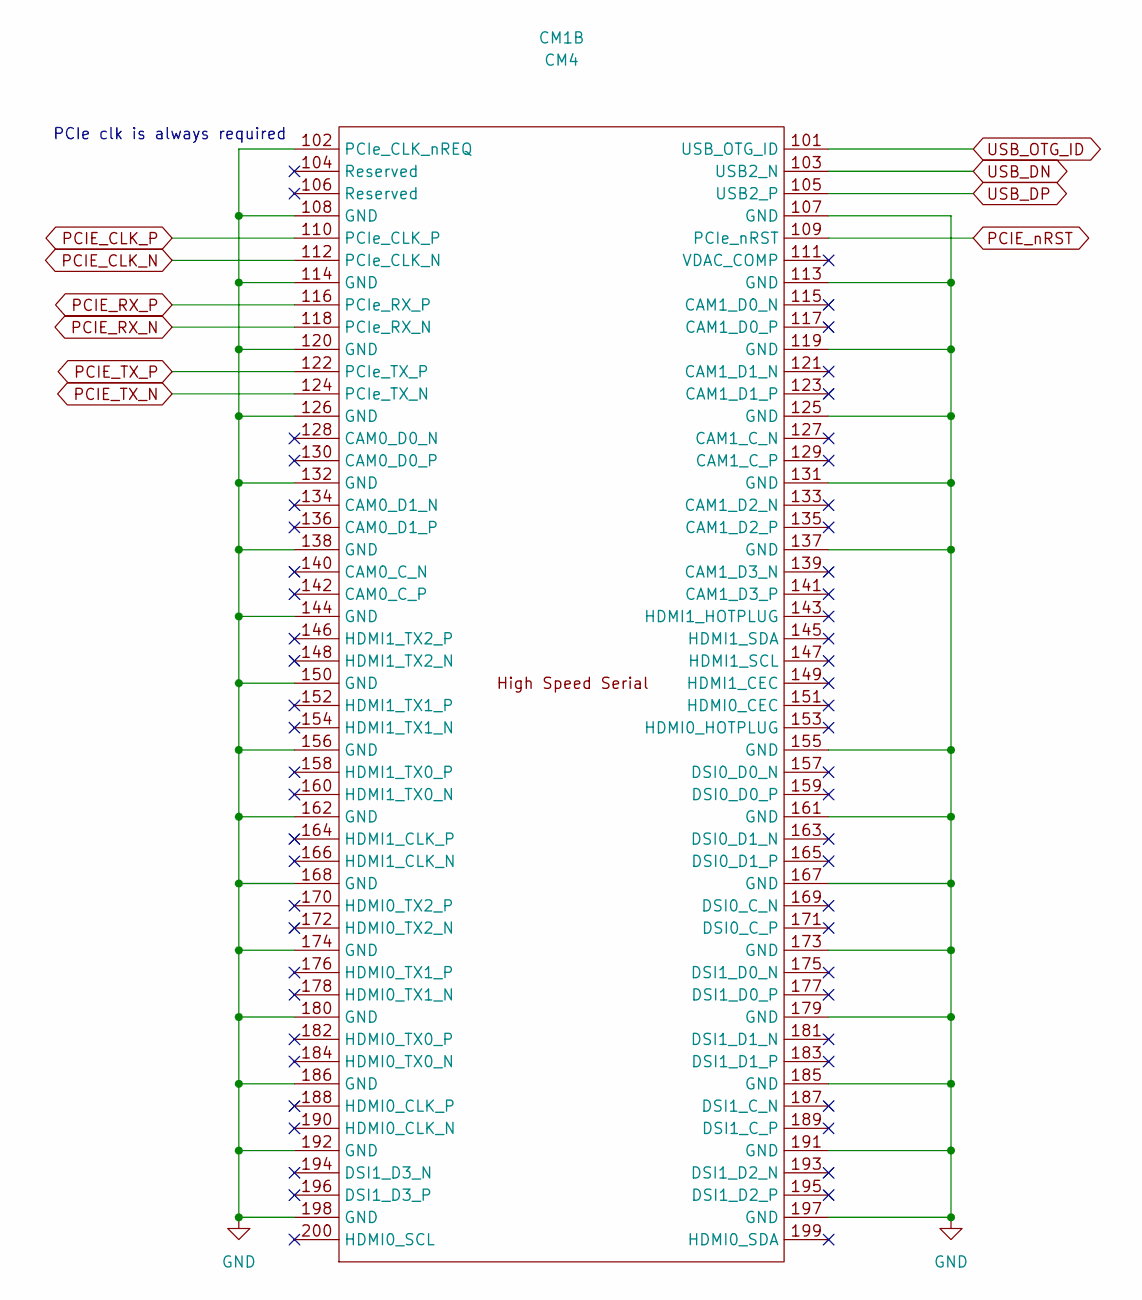
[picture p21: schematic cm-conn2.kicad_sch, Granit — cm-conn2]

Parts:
CM1: CM4; Raspberry-Pi-4-Compute-Module

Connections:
GND: CM1.102 (PCIe_CLK_nREQ), CM1.107 (GND), CM1.108 (GND), CM1.113 (GND), CM1.114 (GND), CM1.119 (GND), CM1.120 (GND), CM1.125 (GND), CM1.126 (GND), CM1.131 (GND), CM1.132 (GND), CM1.137 (GND), CM1.138 (GND), CM1.144 (GND), CM1.150 (GND), CM1.155 (GND), CM1.156 (GND), CM1.161 (GND), CM1.162 (GND), CM1.167 (GND), CM1.168 (GND), CM1.173 (GND), CM1.174 (GND), CM1.179 (GND), CM1.180 (GND), CM1.185 (GND), CM1.186 (GND), CM1.191 (GND), CM1.192 (GND), CM1.197 (GND), CM1.198 (GND); also elsewhere on the board
PCIE_CLK_N: CM1.112 (PCIe_CLK_N); also elsewhere on the board
PCIE_CLK_P: CM1.110 (PCIe_CLK_P); also elsewhere on the board
PCIE_RX_N: CM1.118 (PCIe_RX_N); also elsewhere on the board
PCIE_RX_P: CM1.116 (PCIe_RX_P); also elsewhere on the board
PCIE_TX_N: CM1.124 (PCIe_TX_N); also elsewhere on the board
PCIE_TX_P: CM1.122 (PCIe_TX_P); also elsewhere on the board
PCIE_nRST: CM1.109 (PCIe_nRST); also elsewhere on the board
USB_DN: CM1.103 (USB2_N); also elsewhere on the board
USB_DP: CM1.105 (USB2_P); also elsewhere on the board
USB_OTG_ID: CM1.101 (USB_OTG_ID); also elsewhere on the board

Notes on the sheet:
PCIe clk is always required

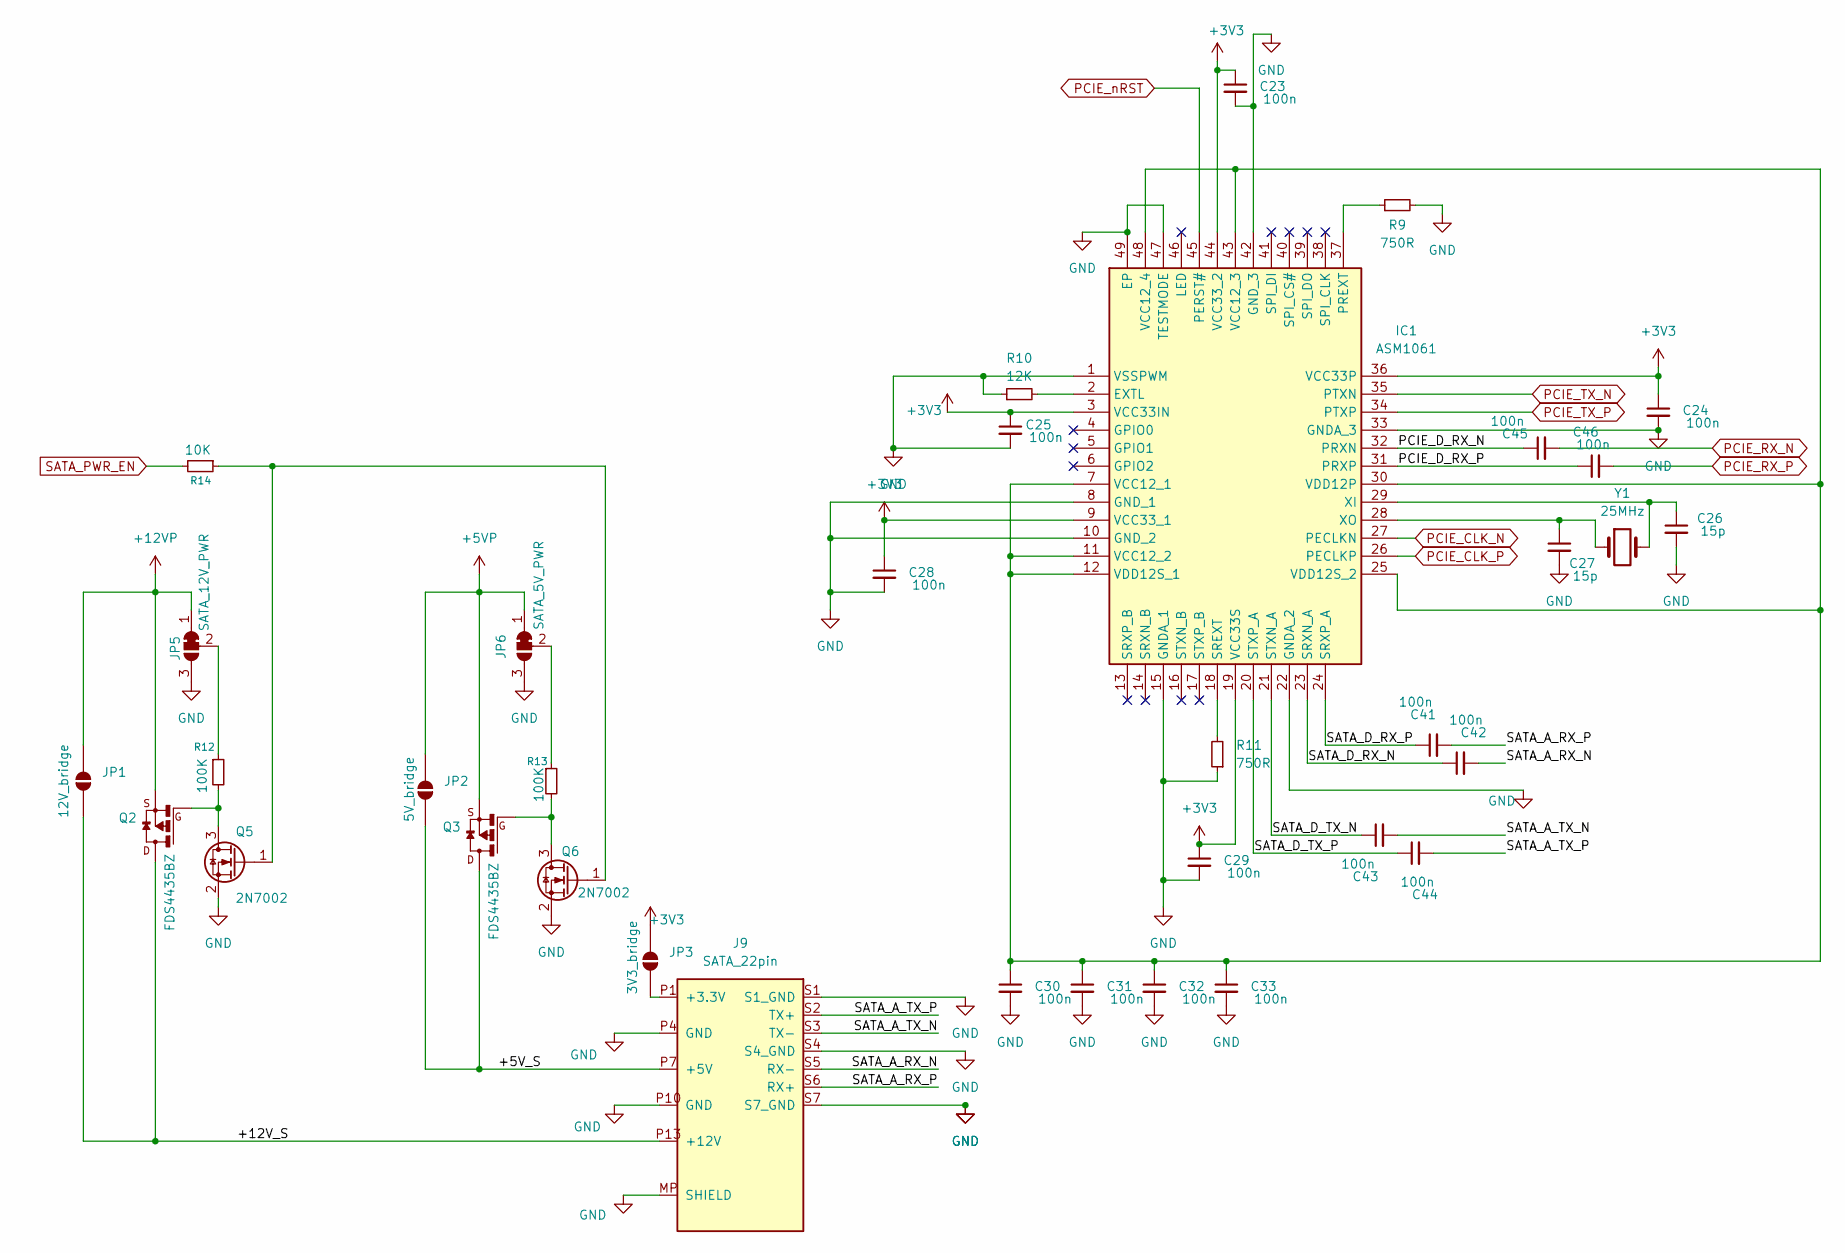
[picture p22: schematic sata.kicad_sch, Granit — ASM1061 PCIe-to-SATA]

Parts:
C23, C24, C25, C28, C29, C30, C31, C32, C33, C41, C42, C43, C44, C45, C46: 100n; C_0805_2012Metric; Digikey 1276-1180-1-ND
C26, C27: 15p; C_0805_2012Metric; Digikey 1276-1180-1-ND
IC1: ASM1061; QFN50P700X700X90-49N-D; Manufacturer_Part_Number ASM1061
J9: SATA_22pin; SATA_Amphenol_10029364-001LF_Horizontal
JP1: 12V_bridge; SolderJumper-2_P1.3mm_Open_Pad1.0x1.5mm
JP2: 5V_bridge; SolderJumper-2_P1.3mm_Open_Pad1.0x1.5mm
JP3: 3V3_bridge; SolderJumper-2_P1.3mm_Open_Pad1.0x1.5mm
JP5: SATA_12V_PWR; SolderJumper-3_P1.3mm_Bridged12_Pad1.0x1.5mm
JP6: SATA_5V_PWR; SolderJumper-3_P1.3mm_Bridged12_Pad1.0x1.5mm
Q2, Q3: FDS4435BZ; SO08-E3
Q5, Q6: 2N7002; SOT-23
R9, R11: 750R; R_0805_2012Metric
R10: 12K; R_0805_2012Metric
R12, R13: 100K; R_0805_2012Metric
R14: 10K; R_0805_2012Metric
Y1: 25MHz; Crystal_SMD_3215-2Pin_3.2x1.5mm

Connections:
+3V3: C23.1, C24.1, C25.1, C28.1, C29.1, IC1.3 (VCC33IN), IC1.9 (VCC33_1), IC1.19 (VCC33S), IC1.36 (VCC33P), IC1.44 (VCC33_2), JP3.2 (B); also elsewhere on the board
+5VP: JP2.2 (B), JP6.1 (A), Q3.1-3; also elsewhere on the board
+12VP: JP1.2 (B), JP5.1 (A), Q2.1-3; also elsewhere on the board
/SATA Bridge/+5V_S: J9.P7 (+5V), J9.P8 (+5V), J9.P9 (+5V), JP2.1 (A), Q3.5-8
/SATA Bridge/+12V_S: J9.P13 (+12V), J9.P14 (+12V), J9.P15 (+12V), JP1.1 (A), Q2.5-8
/SATA Bridge/PCIE_D_RX_N: C45.1, IC1.32 (PRXN)
/SATA Bridge/PCIE_D_RX_P: C46.1, IC1.31 (PRXP)
/SATA Bridge/SATA_A_RX_N: C42.2, J9.S5 (RX-)
/SATA Bridge/SATA_A_RX_P: C41.2, J9.S6 (RX+)
/SATA Bridge/SATA_A_TX_N: C43.2, J9.S3 (TX-)
/SATA Bridge/SATA_A_TX_P: C44.2, J9.S2 (TX+)
/SATA Bridge/SATA_D_RX_N: C42.1, IC1.23 (SRXN_A)
/SATA Bridge/SATA_D_RX_P: C41.1, IC1.24 (SRXP_A)
/SATA Bridge/SATA_D_TX_N: C43.1, IC1.21 (STXN_A)
/SATA Bridge/SATA_D_TX_P: C44.1, IC1.20 (STXP_A)
GND: C23.2, C24.2, C25.2, C26.2, C27.2, C28.2, C29.2, C30.2, C31.2, C32.2, C33.2, IC1.1 (VSSPWM), IC1.8 (GND_1), IC1.10 (GND_2), IC1.15 (GNDA_1), IC1.22 (GNDA_2), IC1.33 (GNDA_3), IC1.42 (GND_3), IC1.47 (TESTMODE), IC1.49 (EP), J9.MP (SHIELD), J9.P4 (GND), J9.P5 (GND), J9.P6 (GND), J9.P10 (GND), J9.P11 (GND), J9.P12 (GND), J9.S1 (S1_GND), J9.S4 (S4_GND), J9.S7 (S7_GND), JP5.3 (B), JP6.3 (B), Q5.2 (S), Q6.2 (S), R9.2, R10.1, R11.1; also elsewhere on the board
unnamed: IC1.2 (EXTL), R10.2
unnamed: IC1.37 (PREXT), R9.1
unnamed: IC1.18 (SREXT), R11.2
unnamed: C30.1, C31.1, C32.1, C33.1, IC1.7 (VCC12_1), IC1.11 (VCC12_2), IC1.12 (VDD12S_1), IC1.25 (VDD12S_2), IC1.30 (VDD12P), IC1.43 (VCC12_3), IC1.48 (VCC12_4)
unnamed: C26.1, IC1.29 (XI), Y1.2
unnamed: C27.1, IC1.28 (XO), Y1.1
unnamed: J9.P1 (+3.3V), J9.P2 (+3.3V), J9.P3 (+3.3V), JP3.1 (A)
unnamed: JP5.2 (C), R12.1
unnamed: JP6.2 (C), R13.1
unnamed: Q2.4, Q5.3 (D), R12.2
unnamed: Q5.1 (G), Q6.1 (G), R14.1
unnamed: Q3.4, Q6.3 (D), R13.2
PCIE_CLK_N: IC1.27 (PECLKN); also elsewhere on the board
PCIE_CLK_P: IC1.26 (PECLKP); also elsewhere on the board
PCIE_RX_N: C45.2; also elsewhere on the board
PCIE_RX_P: C46.2; also elsewhere on the board
PCIE_TX_N: IC1.35 (PTXN); also elsewhere on the board
PCIE_TX_P: IC1.34 (PTXP); also elsewhere on the board
PCIE_nRST: IC1.45 (PERST#); also elsewhere on the board
SATA_PWR_EN: R14.2; also elsewhere on the board

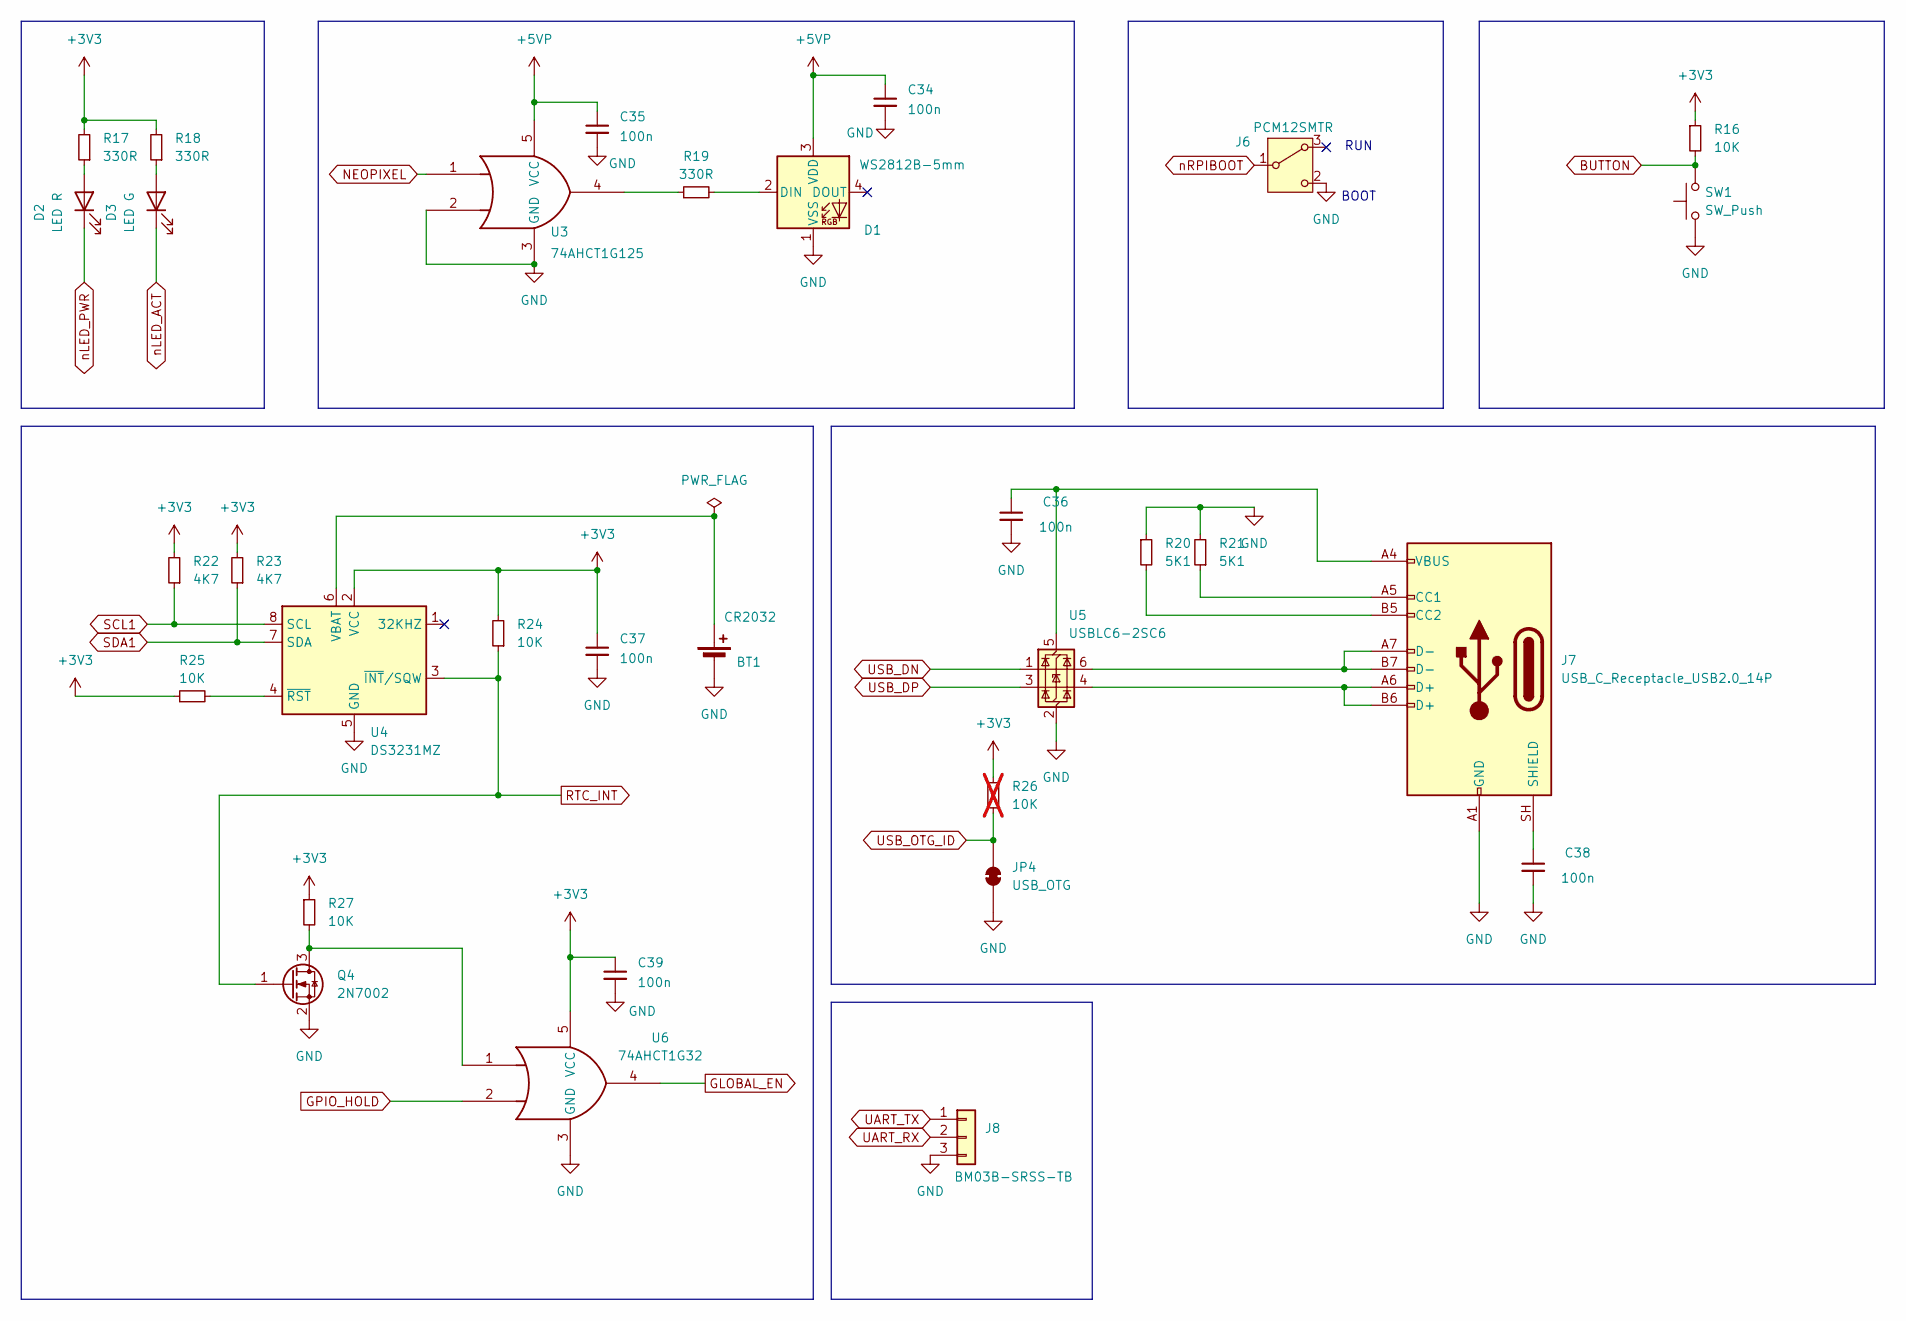
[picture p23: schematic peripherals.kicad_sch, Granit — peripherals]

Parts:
BT1: CR2032; BatteryHolder_Keystone_103_1x20mm
C34, C35, C36, C37, C38, C39: 100n; C_0805_2012Metric; Digikey 1276-1180-1-ND
D1: WS2812B-5mm; LED_WS2812B_PLCC4_5.0x5.0mm_P3.2mm
D2: LED R; LED_0805_2012Metric
D3: LED G; LED_0805_2012Metric
J6: PCM12SMTR; SW_SPDT_PCM12
J7: USB_C_Receptacle_USB2.0_14P; USB_C_Receptacle_GCT_USB4105-xx-A_16P_TopMnt_Horizontal
J8: BM03B-SRSS-TB; JST_SH_BM03B-SRSS-TB_1x03-1MP_P1.00mm_Vertical
JP4: USB_OTG; SolderJumper-2_P1.3mm_Bridged_Pad1.0x1.5mm
Q4: 2N7002; SOT-23
R16, R24, R25, R27: 10K; R_0805_2012Metric
R17, R18, R19: 330R; R_0805_2012Metric
R20, R21: 5K1; R_0805_2012Metric
R22, R23: 4K7; R_0805_2012Metric
R26: 10K; R_0805_2012Metric; not fitted
SW1: SW_Push; SW_Push_1P1T-MP_NO_Horizontal_Alps_SKRTLAE010
U3: 74AHCT1G125; SOT-23-5
U4: DS3231MZ; SOIC-8_3.9x4.9mm_P1.27mm
U5: USBLC6-2SC6; SOT-23-6
U6: 74AHCT1G32; SOT-23-5

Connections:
+3V3: C37.1, C39.1, R16.1, R17.2, R18.2, R22.2, R23.2, R24.2, R25.1, R26.1, R27.1, U4.2 (VCC), U6.5 (VCC); also elsewhere on the board
+5VP: C34.1, C35.1, D1.3 (VDD), U3.5 (VCC); also elsewhere on the board
BUTTON: R16.2, SW1.2; also elsewhere on the board
GLOBAL_EN: U6.4; also elsewhere on the board
GND: BT1.2 (-), C34.2, C35.2, C36.2, C37.2, C38.2, C39.2, D1.1 (VSS), J6.2 (C), J7.A1 (GND), J7.A12 (GND), J7.B1 (GND), J7.B12 (GND), J8.3, JP4.1 (A), Q4.2 (S), R20.1, R21.2, SW1.1, U3.2, U3.3 (GND), U4.5 (GND), U5.2 (GND), U6.3 (GND); also elsewhere on the board
GPIO_HOLD: U6.2; also elsewhere on the board
NEOPIXEL: U3.1; also elsewhere on the board
unnamed: BT1.1 (+), U4.6 (VBAT)
unnamed: D1.2 (DIN), R19.2
unnamed: D2.2 (A), R17.1
unnamed: D3.2 (A), R18.1
unnamed: J7.A5 (CC1), R21.1
unnamed: J7.B5 (CC2), R20.2
unnamed: J7.A6 (D+), J7.B6 (D+), U5.4 (I/O2)
unnamed: J7.A7 (D-), J7.B7 (D-), U5.6 (I/O1)
unnamed: C38.1, J7.SH (SHIELD)
unnamed: Q4.3 (D), R27.2, U6.1
unnamed: R19.1, U3.4
unnamed: R25.2, U4.4 (~RST)
unnamed: C36.1, J7.A4 (VBUS), J7.A9 (VBUS), J7.B4 (VBUS), J7.B9 (VBUS), U5.5 (VBUS)
RTC_INT: Q4.1 (G), R24.1, U4.3 (~INT/SQW); also elsewhere on the board
SCL1: R22.1, U4.8 (SCL); also elsewhere on the board
SDA1: R23.1, U4.7 (SDA); also elsewhere on the board
UART_RX: J8.2; also elsewhere on the board
UART_TX: J8.1; also elsewhere on the board
USB_DN: U5.1 (I/O1); also elsewhere on the board
USB_DP: U5.3 (I/O2); also elsewhere on the board
USB_OTG_ID: JP4.2 (B), R26.2; also elsewhere on the board
nLED_ACT: D3.1 (K); also elsewhere on the board
nLED_PWR: D2.1 (K); also elsewhere on the board
nRPIBOOT: J6.1 (B); also elsewhere on the board

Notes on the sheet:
BOOT
RUN

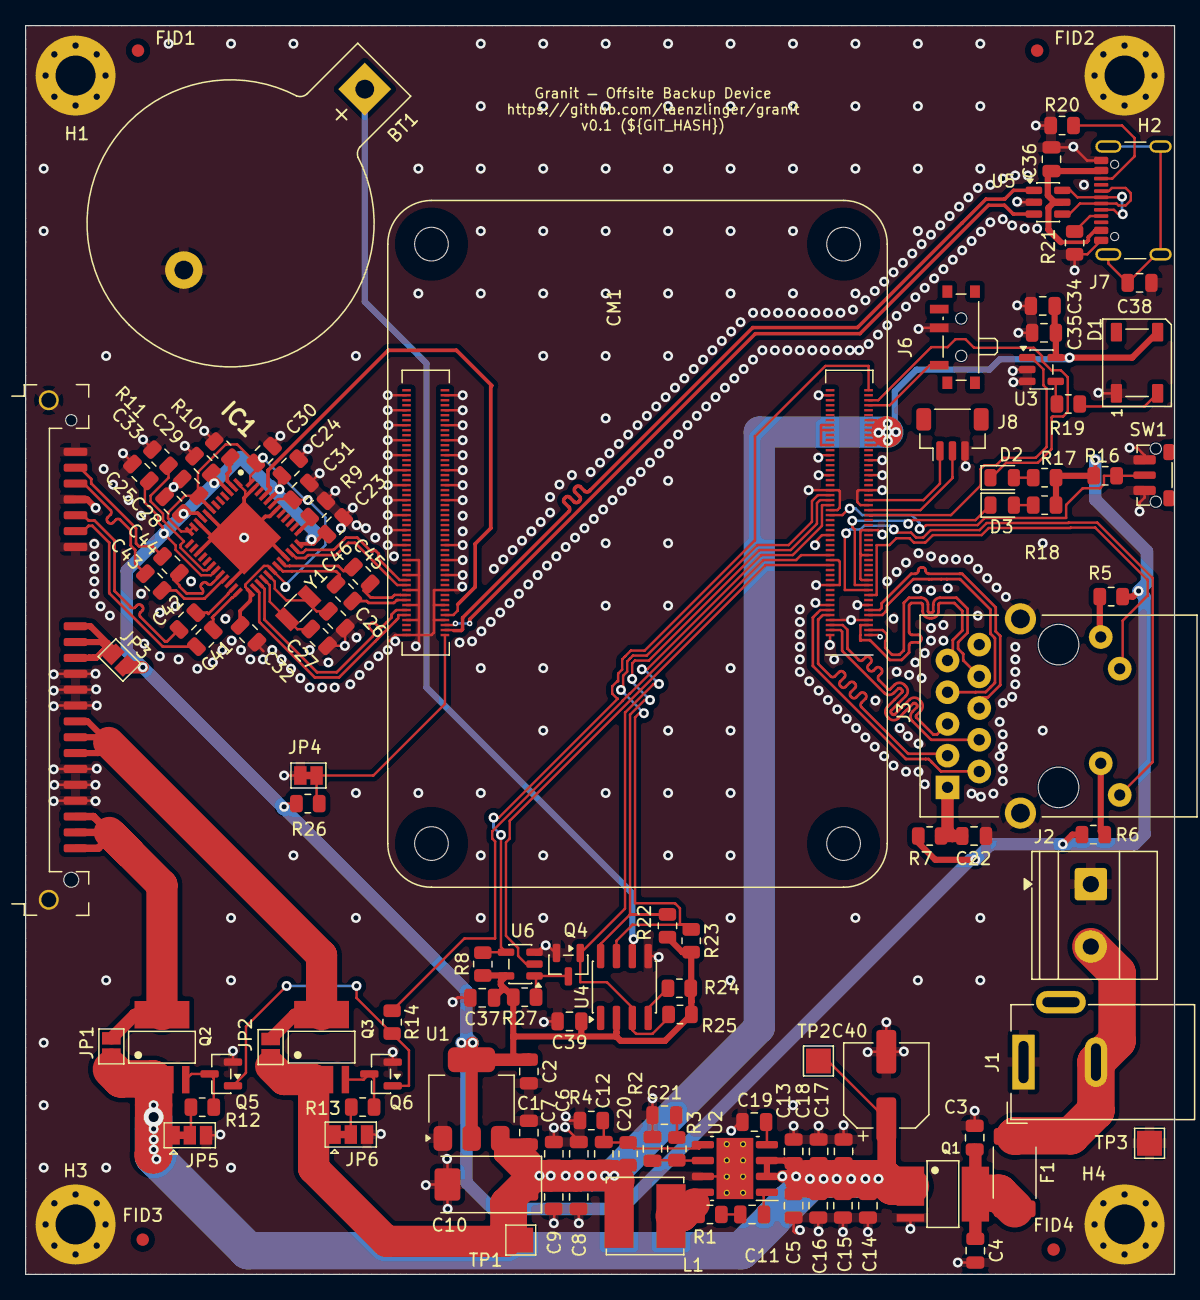
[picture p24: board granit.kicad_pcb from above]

Board: 4 copper layers, 92.0 x 100.0 mm, 118 parts (0 on the bottom side), 87 nets.

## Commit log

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2026-04-07 Switch from JMS578 USB-to-SATA to ASM1061 PCIe-to-SATA
    No proprietary firmware blob required. Native AHCI driver in Linux.
    SMART works directly without SAT translation.
    4-layer PCB with 100Ω differential impedance for PCIe Gen 2.
    [sata.kicad_sch]
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2026-04-07 PSU: reuse pedalboard-hw power supply design
    - Copy AP64351 and FDS4435BZ symbols to granit library
    - Copy barrel jack, SO08-E3, and SOIC-8 footprints from pedalboard-hw
    - Update schematic references from pedalboard to granit library
    - Update README: CM4-only target, both barrel jack and screw terminal
    - Add .kiro/ to .gitignore
    [cm.kicad_sch, granit.kicad_sch, psu.kicad_sch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]
2026-04-07 PSU: sync embedded symbols with library to fix ERC warnings
    [psu.kicad_sch]
2026-04-07 Split CM4 into separate connector sheets, add peripherals sheet
    Sheet structure:
    - psu.kicad_sch (Power Supply)
    - cm-conn1.kicad_sch (CM4 Connector 1: power, USB, HDMI)
    - cm-conn2.kicad_sch (CM4 Connector 2: PCIe, Ethernet, GPIO, I2C)
    - sata.kicad_sch (ASM1061 PCIe-to-SATA)
    - peripherals.kicad_sch (RTC, LED, button)
    [cm-conn1.kicad_sch, cm-conn2.kicad_sch, granit.kicad_sch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]
2026-04-07 CM4 connectors: add symbols/footprints, connect power pins
    - Copy CM4 symbol and footprint from pedalboard-hw to granit library
    - Remove all pedalboard library references
    - Connect GND and +5V power pins on both connectors
    - PSU GND ERC error resolved
    - 0 ERC warnings, remaining errors are expected unconnected signal pins
    [cm-conn1.kicad_sch, cm-conn2.kicad_sch, granit.kicad_sch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]
2026-04-07 CI: add KiCad 10 compatibility workaround for kicad9_auto
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2026-04-07 CI: use KiBot dev branch with KiCad 10 support
    KiBot 1.8.6 (dev) can parse KiCad 10 files.
    Install from git dev branch + KiCad 10 PPA on ubuntu-latest.
    [cm-conn1.kicad_sch, cm-conn2.kicad_sch]
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2026-04-07 CM4 connectors: NC unused pins (HDMI, DSI, Camera, SD, GPIOs, misc)
    Remaining unconnected pins are all signals to wire:
    - Ethernet (8 data + 5 control)
    - USB OTG (3 pins)
    - PCIe (8 pins)
    - GPIOs for peripherals (7 pins: I2C, UART, button, NeoPixel)
    - Status LEDs, nRPIBOOT
    [cm-conn1.kicad_sch, cm-conn2.kicad_sch]
2026-04-07 CM4 connectors: NC all unused pins
    Remaining 43 pins are all signals to wire:
    - GPIOs: I2C1 (2), UART (2), button (1), NeoPixel (1), RTC INT (1)
    - Status LEDs (2), nRPIBOOT (1)
    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
    [cm-conn1.kicad_sch]
2026-04-07 CM4 Connector 1: add global labels for all signals
    Ethernet, GPIOs (I2C, UART, button, NeoPixel, RTC INT),
    status LEDs, nRPIBOOT — all labeled and connected.
    [cm-conn1.kicad_sch]
2026-04-07 CM4 Connector 2: add global labels for USB, PCIe signals
    Both CM4 connector sheets fully labeled. Remaining 9 ERC
    errors are expected — inputs not yet driven by other sheets.
    [cm-conn2.kicad_sch]
2026-04-07 Peripherals: add status LEDs, NeoPixel with 74AHCT1G125 level shifter
    - Power LED (nLED_PWR) and activity LED (nLED_ACT) with resistors, DNP
    - SK6812MINI-E NeoPixel with 74AHCT1G125 3.3V→5V level shifter
    - 300Ω series resistor on NeoPixel data line
    - 9 ERC errors remaining, all expected (undriven inputs on other sheets)
    [peripherals.kicad_sch]
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2026-04-07 Peripherals: add DS3231MZ RTC with CR2032 battery backup
    - DS3231MZ (SO-8) with I2C pull-ups (4.7kΩ)
    - CR2032 battery holder for VBAT + PWR_FLAG
    - INT/SQW connected to RTC_INT with pull-up
    - 100nF decoupling cap on VCC
    - Peripherals sheet complete: LEDs, NeoPixel, button, UART,
    nRPIBOOT header, RTC
    [peripherals.kicad_sch]
2026-04-07 TODO: add missing footprints and component fixes
2026-04-08 Peripherals: add USB-C OTG with USBLC6-2SC6 ESD protection
    - USB-C receptacle (USB 2.0 only)
    - USBLC6-2SC6 ESD protection on D+/D-
    - 5.1kΩ CC pull-downs for device/sink identification
    - USB_OTG_ID tied low for device mode
    - 100nF shield-to-GND coupling cap
    - Peripherals sheet complete
    [peripherals.kicad_sch]
2026-04-08 Ethernet: add RB1-125B8G1A Gigabit MagJack with LEDs
    - RJ45 with integrated magnetics (10/100/1000 BaseT)
    - 4 differential pairs connected to CM4 Ethernet PHY
    - Center tap biased via 10Ω + 100nF to 3.3V
    - Green/Yellow LEDs wired to ETH_nLED1/nLED2
    - ETH_SYNC_IN/OUT and ETH_nLED3 NC'd
    [cm-conn1.kicad_sch, peripherals.kicad_sch]
2026-04-08 SATA: place ASM1061, connect GND and power pins
    - ASM1061 symbol + footprint from Component Search Engine
    - All GND pins connected (including EP and VSSPWM)
    - 3.3V pins connected with 100nF decoupling caps
    - 1.2V internal regulator pins tied together
    - 29 ASM1061 pins remaining (PCIe, SATA, crystal, misc)
    [ASM1061.stp, sata.kicad_sch]
2026-04-08 SATA: ASM1061 fully wired
    - PCIe data, clock, and reset connected via global labels
    - 25MHz crystal with load caps
    - SATA Port A connected to 7-pin data connector
    - SATA Port B NC'd
    - Impedance calibration resistors (SREXT 750Ω, PREXT 750Ω, EXTL 12kΩ)
    - SPI flash pins NC'd (no firmware needed)
    - TESTMODE tied to GND
    - All decoupling caps placed (5x 3.3V, 4x 1.2V)
    - 6 ERC errors remaining (ETH_SYNC NC, PCIe_CLK_nREQ, USB_OTG_ID)
    [sata.kicad_sch]
2026-04-08 Clean up ERC: PWR_FLAGs, OTG_ID solder jumper, PCIe_CLK_nREQ
    - Add PWR_FLAG on GND net (PSU sheet)
    - USB_OTG_ID: solder jumper to GND with 10K pull-up for host/device mode
    - PCIe_CLK_nREQ tied to GND locally on connector 2
    - 1 ERC error remaining: CM4 dual 3.3V output pins (false positive)
    [cm-conn1.kicad_sch, cm-conn2.kicad_sch, peripherals.kicad_sch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]
2026-04-08 ERC: 0 errors — schematic complete
    All sheets wired and verified:
    - PSU, CM4 Connectors, SATA (ASM1061), Peripherals
    - Fixed CM4 pin 86 type (power_out → passive) to resolve false positive
    - 6 warnings remaining (library references, minor cleanup)
    [cm-conn1.kicad_sch, cm-conn2.kicad_sch]
2026-04-08 ERC: 0 errors, 0 warnings — fully clean
    - Fix ASM1061 footprint reference (granit:QFN50P700X700X90-49N-D)
    - Fix CM4 embedded symbol references (pedalboard → granit)
    - Sync ASM1061 embedded symbol with library
    - Remove dangling no-connect flags
    - Re-add NC for barrel jack switch pin (J7 pin 3)
    [cm-conn1.kicad_sch, cm-conn2.kicad_sch, psu.kicad_sch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]
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2026-04-08 Add GLOBAL_EN pull-up for software suspend wake, FIXME for hardware latch
    - 10kΩ pull-up on GLOBAL_EN to 3.3V (always-on, software suspend)
    - TODO: alternative MOSFET latch for hardware power-off wake
    - ERC: 0 errors, 0 warnings
    [cm-conn1.kicad_sch, cm-conn2.kicad_sch, psu.kicad_sch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]
2026-04-08 SATA: add power connector (12V, 5V, 3.3V, GND)
    - 12V passthrough from PSU (after polarity protection)
    - 5V from AP64501SP-13 buck
    - 3.3V from NCP1117 LDO (for completeness)
    - FIXME: TPM/crypto chip added to TODO
    [psu.kicad_sch, sata.kicad_sch]
2026-04-08 Fix net name conflict: use +12VP consistently
    [psu.kicad_sch]
2026-04-08 PSU: replace polyfuse with SMD fuse (Device:Fuse)
    [psu.kicad_sch]
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2026-04-08 Assign footprints to all components
    All components now have valid footprints:
    - 0805 for all resistors, caps, LEDs
    - SOT-23-5/6 for ICs
    - 2512 SMD fuse, 3215 crystal
    - Pin headers, USB-C, solder jumper, battery holder
    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
    [cm-conn1.kicad_sch, peripherals.kicad_sch, psu.kicad_sch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]
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2026-04-08 Standardize all resistors to R_Small, fix broken R22 connection
    [cm-conn1.kicad_sch, peripherals.kicad_sch, sata.kicad_sch]
2026-04-08 Add descriptions to all major components for BOM documentation
    ICs, connectors, passives with specific roles, and DNP parts
    now have meaningful descriptions in the schematic properties.
    [cm-conn1.kicad_sch, cm-conn2.kicad_sch, peripherals.kicad_sch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]
2026-04-08 Consolidate LED resistors to 330R, eliminate 220R value
    R13, R14 (status LEDs): 2K2 → 330R
    R15 (NeoPixel data): 220R → 330R
    9 unique resistor values (was 10)
    [peripherals.kicad_sch]
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2026-04-08 Set USB OTG_ID pull-up resistor to DNP (only needed in host mode)
    [peripherals.kicad_sch]
2026-04-08 FDS4435BZ: hide pin numbers, fix footprint refs, add SATA_PWR_EN label
    - Clean up FDS4435BZ symbol (hidden pin numbers)
    - Fix Pedalboard Library → granit footprint references
    - Sync embedded symbols with library
    - GPIO5 labeled as SATA_PWR_EN for future power switching
    - 1 warning: isolated SATA_PWR_EN (pending SATA FET placement)
    [cm-conn1.kicad_sch, psu.kicad_sch]
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2026-04-08 SATA: add power switching circuit (DNP) with solder jumper bypass
    - Q2 (FDS4435BZ, DNP): 5V SATA power switch
    - Q3 (FDS4435BZ, DNP): 12V SATA power switch
    - Solder jumpers for v1 bypass (bridged = power always on)
    - Gate resistors and pull-ups for GPIO5 control
    - SATA_PWR_EN global label connected
    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
    [psu.kicad_sch, sata.kicad_sch]
2026-04-08 SATA: fix power switching wiring, verify all connections
    - 5V and 12V on separate nets (was shorted)
    - Gate resistors (R23, R24 10K) connected to SATA_PWR_EN
    - Pull-ups (R25 100K to 12V, R26 100K to 5V) on gates
    - All DNP for v1, solder jumpers bypass FETs
    - Netlist verified: all connections correct
    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
    [sata.kicad_sch]
2026-04-08 Replace 74AHCT1G125 with 74AHCT1G32 for NeoPixel level shifter
    OR gate with input B tied to GND acts as buffer.
    Same AHCT family, same SOT-23-5 package.
    Enables reuse of same part for wake circuit.
    [peripherals.kicad_sch]
2026-04-08 Add hardware wake circuit: 2N7002 + 74AHCT1G32 OR gate
    RTC alarm → N-FET inverter → OR gate → GLOBAL_EN
    GPIO6 (GPIO_HOLD) keeps CM4 alive after boot.
    All wake components DNP for v1 (pull-up fallback).
    v2: populate wake circuit, remove GLOBAL_EN pull-up.
    ERC: 0 errors, 0 warnings
    [cm-conn1.kicad_sch, peripherals.kicad_sch]
2026-04-08 Add missing decoupling caps: wake OR gate, NeoPixel OR gate, SK6812
    - C37: 100nF on U3 (NeoPixel OR gate, 5V)
    - C38: 100nF on D1 (SK6812MINI-E VDD, 5V)
    - C39: 100nF on U6 (wake OR gate, 3.3V)
    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
    [peripherals.kicad_sch]
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2026-04-08 Merge parts.md into README and TODO
    - README: SATA connector part number, Hammond 1455 case comparison table
    - TODO: mounting hole specs, footprint names, keepout clearances, SATA orientation check, power trace width, enclosure tasks
    - Remove parts.md (merged)
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2026-04-09 Battery fallback: CR1220 on bottom if top side space is tight
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2026-04-09 Setup KiCad net classes: PCIe, SATA, Ethernet, USB, Power
    - PCIe/SATA: 0.6mm clearance, 0.2mm diff pair gap/width
    - Ethernet/USB: 0.4mm clearance, 0.2mm diff pair gap/width
    - Power: 1.0mm track, 1.6mm via
    - Net patterns auto-assign by signal name
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2026-04-09 Add SATA diff pair labels with _P/_N suffix for KiCad auto-pairing
    - SATA_A_TX_P/N, SATA_A_RX_P/N on port A wires
    - Updated netclass patterns: SATA_A_*, SATA_B_*
    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
    [sata.kicad_sch]
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2026-04-09 Fix stackup: prepreg Er=4.4 (not 4.6), add solder mask parameters
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2026-04-09 Setup 4-layer PCB with JLCPCB JLC04161H-7628 stackup
    - F.Cu (1oz/35µm) / prepreg 7628 (0.2104mm, Er=4.4) / In1.Cu (0.5oz)
    - Core (1.065mm, Er=4.6)
    - In2.Cu (0.5oz) / prepreg 7628 (0.2104mm, Er=4.4) / B.Cu (1oz/35µm)
    - Solder mask Er=3.8, dielectric constraints enabled
    - Board outline: 71 x 101mm
    - Total thickness: 1.59mm
    [granit.kicad_pcb]
2026-04-09 Fix 4-layer stackup: move inside setup block for KiCad 10
    [granit.kicad_pcb]
2026-04-09 Set solder mask/paste parameters for JLCPCB
    - Mask expansion: 0.05mm
    - Min mask bridge: 0.1mm
    - Paste margin: -0.05mm (shrink to prevent bridging)
    [granit.kicad_pcb]
2026-04-09 Use -10% paste ratio instead of fixed margin (better for fine-pitch)
    [granit.kicad_pcb]
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2026-04-09 Assign missing footprints: R12-R15 (0805), JP1-JP3 (solder jumper), U6 (SOT-23-5)
    [peripherals.kicad_sch, sata.kicad_sch]
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2026-04-09 Add SATA_22pin symbol (Amphenol 10029364-001LF) + 3D model
    - 7 data pins (S1-S7): TX+/-, RX+/-, GND
    - 15 power pins (P1-P15): +3.3V, GND, +5V, GND, +12V
    - MP: shield
    - Footprint: Connector_SATA_SAS:SATA_Amphenol_10029364-001LF_Horizontal
    [i10029364001LF.igs]
2026-04-09 Replace SATA data+power connectors with single Amphenol 22-pin
    - New granit:SATA_22pin symbol with correct pin types
    - Rewired SATA schematic with combined connector (J9)
    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
    [sata.kicad_sch]
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2026-04-09 Fix ASM1061 footprint library prefix (granit:QFN50P700X700X90-49N-D)
    [sata.kicad_sch]
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2026-04-09 Add OpenSCAD mechanical assembly (case + PCB + HDD)
    Clearances for Hammond 1455L2201:
    - HDD-to-ceiling: 1.9mm
    - PCB-to-ceiling: 23.4mm
    - Length: 71 + 2 + 147 = 220mm (exact fit)
    [assembly.scad]
2026-04-09 Replace OpenSCAD with STEP exports for FreeCAD assembly
    - Exported PCB STEP to mechanical/granit-pcb.step
    - Hammond 1455L2201.stp already in 3d-models/
    - Assemble in FreeCAD with real models
    [assembly.scad, granit-pcb.step]
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2026-04-09 Fix: make all assembly parts visible in FreeCAD
2026-04-09 Fix FreeCAD assembly: proper STEP imports, HDD model, positioning
    [3.5inch_HDD_NAS.step]
2026-04-09 Fix assembly: correct case rotation, PCB origin offset, HDD position
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2026-04-09 Enclosure: 3D-printed frame slides into card guides, replaces CNC belly plate
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2026-04-09 Fix assembly rotations: PCB and HDD aligned to case axes
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2026-04-09 PCB layout prep: resize to 92x100mm, fix 3D models, dual assembly variants
    - Resize PCB from 71x99mm to 92x100mm for Hammond 1455 enclosures
    - Update wide enclosure from 1455T2201 to 1455T2601 (260mm) for 3.5" HDD
    - Download CM4 3D model, create AP64501 stand-in, fix KICAD6->KICAD10 paths
    - Generate 1455T2601 STEP by scaling T2201
    - Create 2.5" HDD placeholder model with SATA recess
    - Rewrite assembly script for slim (1455L+2.5") and wide (1455T+3.5") variants
    - Render 4K assembly screenshots with software OpenGL
    - Update README with new enclosure specs and both assembly images
    [1455T2601.stp, 2.5inch_HDD.step, SO-8EP.STP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]
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2026-04-09 Replace reverse-mount LED with standard 5050 SK6812 for light pipe
    [granit.kicad_pcb, peripherals.kicad_sch]
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2026-04-09 Fix MOSFET 3D model paths: KICAD6 → KICAD10, .wrl → .step
    [granit.kicad_pcb]
2026-04-09 Fix fuse 3D model: use R_2512 (same package size)
    [granit.kicad_pcb]
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2026-04-09 Fix ASM1061 3D model path
    [granit.kicad_pcb]
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2026-04-10 Set all net class clearances to 0.2mm for CM4 pad compatibility
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2026-04-10 Fix ERC: update SK6812 symbol to match library
    [peripherals.kicad_sch, sata.kicad_sch]
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2026-04-10 Fix CI: use local 3D model for U2 AP64501 (not in KiCad 10 3D lib)
    [granit.kicad_pcb]
2026-04-10 CI: remove 3D renders (pcbnew_do incompatible with headless KiCad 10)
2026-04-10 CI: revert to kicad:10.0 image, skip 3D renders until INTI-CMNB kicad10 image exists
2026-04-10 Update TODO: add 3D render FIXME, fix PCB size
2026-04-10 SATA power: add N-FET level shifters, solder jumpers, split power netclasses
    - Add Q5, Q6 (2N7002) as level shifters between GPIO17 and P-FET gates
    (Q2/Q3). GPIO at 3.3V cannot directly switch P-FETs with 12V/5V sources.
    - Add JP5 (SATA_12V_PWR), JP6 (SATA_5V_PWR) 3-pad solder jumpers to
    select boot default: pads 1-2 bridged = HDD off (default), pads 2-3
    bridged = HDD on at boot.
    - Add R14 (10K) series gate resistor for GPIO protection against N-FET
    failure.
    - Remove old R14, R15 (10K direct GPIO-to-gate resistors) — replaced by
    N-FET level shifter circuit.
    - Split Power netclass into Power 12V (3.0mm), Power 5V (2.5mm),
    Power 3V3 (1.0mm) sized for 1oz copper with headroom.
    - U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
    [granit.kicad_pcb, sata.kicad_sch]
2026-04-10 Fix mechanical assembly: Part.read() for correct placement, fix PCB/HDD rotations and Z layout
    [psu.kicad_sch, sata.kicad_sch]
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2026-04-10 Fix front panel removal for slim case variant
    [granit.kicad_pcb]
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2026-04-10 Route power supply section
    12V and 5V rails routed on top layer with GND return vias to inner
    planes. Buck converter switching loop (VIN-SW-L1-output caps) kept
    tight on top layer. Power distributed to rest of board via bottom
    layer transitions.
    [granit.kicad_pcb]
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2026-04-11 Swap GPIO_HOLD and SATA_PWR_EN pin assignments for easier routing
    [cm-conn1.kicad_sch]
2026-04-11 Move RTC south of CM4, avoid USB crossing
    [granit.kicad_pcb]
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2026-04-11 Fix fiducial footprint name to Fiducial_1mm_Mask2mm
    [granit.kicad_pcb, granit.kicad_sch]
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2026-04-11 Link mounting holes H1-H4 between schematic and PCB, remove redundant DRC exclusions from DESIGN.md
    - Set footprint assignments for H1-H4 in schematic
    - Add path/sheetname/sheetfile/attr to H1-H4 PCB footprints
    - Set Description field on PCB footprints to match schematic
    - Remove DRC Exclusions section from DESIGN.md (justifications
    live in kicad_pro exclusion comments)
    - Resolves all schematic parity issues (0 remaining)
    [granit.kicad_pcb, granit.kicad_sch]
2026-04-11 Connect mounting holes H1-H4 to GND
    - Change symbols from MountingHole to MountingHole_Pad
    - Wire pad to GND for chassis ground through metal standoffs
    - Update PCB from schematic to sync nets and fields
    - ERC clean, 0 schematic parity issues
    [granit.kicad_pcb, granit.kicad_sch]
2026-04-11 Exclude AP64501 clearance violations, add justification comments to all DRC exclusions
    - Exclude U2 (AP64501) pad 2/3 vs pad 9 clearance — SOIC-8 package
    constraint, Power 12V netclass 0.3mm cannot be met (physical 0.2mm)
    - Exclude SW1 solder mask bridges — NPTH mounting pin proximity
    - Restore justification comments on all 39 DRC exclusions
    - Remaining 30 violations: silk cosmetic (23), starved thermals (6),
    hole-to-hole (1)
2026-04-11 Move J1/J2 to separate locations, resolve silk overlap violations
    - Separate barrel jack (J1) and screw terminal (J2) placement
    - Eliminates silk overlap and silk_over_copper warnings between J1/J2
    - DRC violations reduced from 30 to 23
    - Remaining: silk cosmetic (15), starved thermals (6), hole-to-hole (1),
    lib footprint mismatch (1)
    [granit.kicad_pcb]
2026-04-11 Fix hole-to-hole violation — nudge +5VP via spacing
    DRC violations reduced from 23 to 22. Remaining: silk cosmetic (15),
    starved thermals (6), lib footprint mismatch (1)
    [granit.kicad_pcb]
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2026-04-11 Fix J2 footprint mismatch, PCB cleanup
    DRC violations reduced from 22 to 21. Remaining: silk cosmetic (15),
    starved thermals (6)
    [granit.kicad_pcb]
2026-04-11 Fix 4 of 6 starved thermals, add manual spoke for U2 pad 7
    - Fix starved thermals on U2 pad 9 (B.Cu x2), C27, J8
    - Add manual trace spoke for U2 pad 7 (GND) — no space for formal
    thermal relief due to surrounding SW/inductor routing
    - J3 R10 thermal to be resolved with Ethernet reroute
    - DRC: 17 remaining (15 silk cosmetic, 2 starved thermal)
    [granit.kicad_pcb]
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2026-04-11 Reroute Ethernet pairs without layer crossings, fix J3 starved thermal
    - All Ethernet differential pairs now on single layer without crossings
    - Fix J3 SH starved thermal with reroute
    - DRC: 16 remaining (15 silk cosmetic, 1 starved thermal on U2 pad 7)
    [granit.kicad_pcb]
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2026-04-11 Clean DRC: exclude remaining silk cosmetic violations, fix TP2 and silk issues
    - Fix TP2 silk_over_copper
    - Exclude 12 remaining silk violations (footprint/edge constraints)
    - All 46 DRC exclusions have justification comments
    - ERC: 0 violations, DRC: 0 violations, 0 unconnected, 0 parity issues
    [granit.kicad_pcb]
2026-04-11 Fix missing 3D models: point RJ45, SW1 to local copies, substitute fuse
    - J3 (RJ45): use local 3d-models/RJ45_UDE_RB1-125B8G1A.step
    - SW1 (button): use local 3d-models/SW_Alps_SKRTLAE010.step
    - F1 (fuse): substitute with R_2512_6332Metric (same package size)
    [granit.kicad_pcb]
2026-04-11 Fix 3D model offset and rotation for RJ45, SW1, and fuse
    [granit.kicad_pcb]
2026-04-11 Add 'make render' target for 3D board screenshots
    Renders top and bottom perspective views to out/ using kicad-cli pcb render.
    Workaround until KiBot supports KiCad 10.
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2026-04-11 Fix 3D render angle — tilt down instead of up
2026-04-11 Fix H4 mounting hole position to symmetric 4mm from board edges
    Was at (107.86, 115.20), now at (108, 116) matching H1/H2/H3 pattern.
    Two stale Y1 silk exclusions need re-excluding after zone refill.
    [granit.kicad_pcb]
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2026-04-12 fix: add missing BOM values for F1 (3A), Y1 (25MHz), BT1 (CR2032)
    [peripherals.kicad_sch, psu.kicad_sch, sata.kicad_sch]
2026-04-12 feat: replace J6 with PCM12SMTR slide switch, J8 with JST-SH 3-pin
    J6 (nRPIBOOT): pin header + jumper → SPDT slide switch (SW_SPDT_312)
    J8 (UART debug): 2.54mm pin header → JST-SH SM03B-SRSS-TB (latching)
    [peripherals.kicad_sch]
2026-04-12 fix: J8 use vertical JST-SH (BM03B-SRSS-TB)
    [peripherals.kicad_sch]
2026-04-12 fix: J6/J8 wiring and PCB layout after connector swap
    [cm.kicad_sch, granit.kicad_pcb, granit.kicad_sch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]
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2026-04-12 docs: FIXME J8 UART pinout is TX-RX-GND, should be GND-TX-RX
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2026-04-12 feat: BT1 swap to Keystone 103 (top-insert CR2032 holder)
    [peripherals.kicad_sch]
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2026-04-12 fix: SATA netclass pattern didn't match hierarchical net names
    Pattern was 'SATA_A_*' but nets are '/SATA Bridge/SATA_A_*'.
    Changed to '*SATA_A_*' to match. SATA traces need re-routing at
    correct 0.2205mm diff pair width.
2026-04-12 fix: re-route SATA diff pairs at correct 0.2205mm width
    [granit.kicad_pcb]
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2026-04-12 feat: add automated tests (RTC temp, PCIe link, SATA r/w, UART loopback, dmesg)
    New tests:
    - DS3231 temperature sensor readback (I2C data integrity)
    - RTC set/read roundtrip
    - PCIe link speed (Gen 2) and width (x1) verification
    - SATA read/write integrity test (optional, user-confirmed)
    - UART TX→RX loopback (requires jumper wire on J8)
    - dmesg scan for SATA/PCIe/I2C/USB/ETH errors
2026-04-12 feat: add 6 AC coupling caps (C41-C46, 100nF 0805)
    - C41-C44: SATA TX/RX pairs (STXP_A, STXN_A, SRXP_A, SRXN_A)
    - C45-C46: PCIe RX pair (PCIE_RX_P, PCIE_RX_N)
    All placed near ASM1061 per datasheet requirements.
    ERC: 0 errors, 0 warnings.
    [sata.kicad_sch]
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2026-04-12 feat: place and route AC coupling caps, fix PCIE_D_ netclass width
    [granit.kicad_pcb]
2026-04-12 fix: re-route SATA_D_RX diff pairs at correct 0.2205mm width
    [granit.kicad_pcb]
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2026-04-12 feat: add GND stitching vias (97 new, 2.3/cm²), DRC clean
    Automated placement via add-stitching-vias.py with 0.6mm clearance.
    Zones rebuilt on all 4 layers. 0 DRC violations.
    [granit.kicad_pcb]
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

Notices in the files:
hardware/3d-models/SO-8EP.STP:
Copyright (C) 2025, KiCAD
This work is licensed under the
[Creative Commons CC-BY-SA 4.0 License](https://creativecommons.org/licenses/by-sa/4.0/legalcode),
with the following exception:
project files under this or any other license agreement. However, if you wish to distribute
